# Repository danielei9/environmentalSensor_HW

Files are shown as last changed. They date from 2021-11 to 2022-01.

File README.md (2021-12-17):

# environmentalSensor

# EnvironmentalSensor

El proyecto consta de una placa maestra donde se pueden conectar varios sensores predeterminados como temperatura, humedad, sensor de sustrato y ruido. Esta placa (Master) se comunica mediante I2C con otra placa expansión (Slave) que se comunica con un máximo de 5 sensores de cualquier tipo mediante UART (mirar especificaciones de sensores admitidos).

Una vez adquiridas las medidas de los sensores, se procesan y son enviadas mediante LORA o 4G (gsm).
En el caso de LORA: el dispositivo “Master” envía datos a un Gateway de LORA, donde mediante un Bridge realiza el cambio LORA - MQTT y enviamos los datos a la plataforma
En el caso de 4G: se envía directamente a través de MQTT.
### Master:
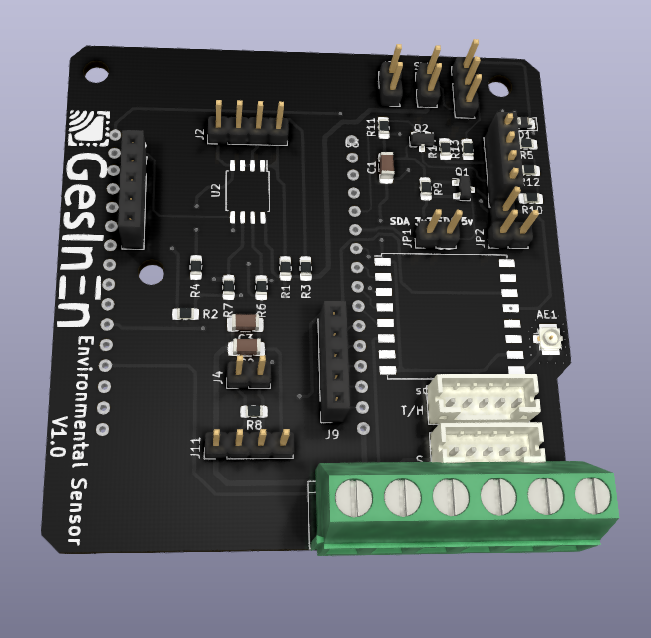
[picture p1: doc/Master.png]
Master


### Slave:

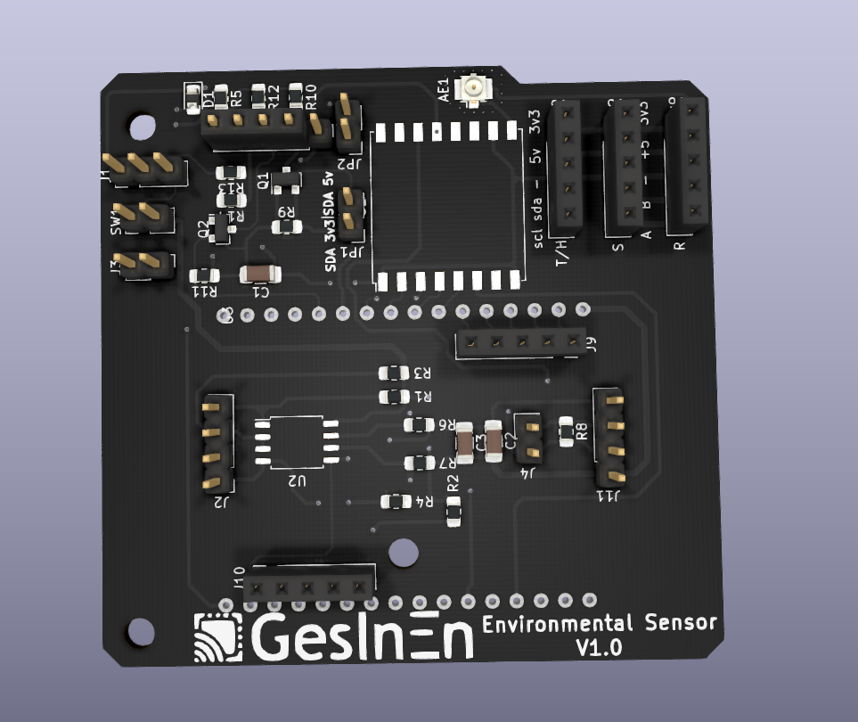
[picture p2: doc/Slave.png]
This is an image


# **Contents**
- [**Project**](#firmware-hardware-module)
- [**Contents**](#contents)
- [**Pre requirements**](#pre-requirements)
- [**Getting started**](#getting-started)
- [**Project structure**](#project-structure)
- [**Firmware**](#firmware)
  - [**Master Code**](#master-code)
  - [**Slave Code**](#slave-code)
  - [**Measures**](#measures)
- [**Deployment**](#deployment)

# **Pre requirements**
This Project is being developed using `Platformio` in Visual Studio Code so you need to have being installed it and dependences. 

- Install Platformio in Visual Studio Code
# **Getting started**
1. Clone the repository
```
git clone https://github.com/ycansam/environmentalSensor_HW
```
Now you can start with the implementation of new features to comunicate with the ttgo and arduino nano

# **Project structure**
```
environmentalSensor_HW/
    ├──  doc/
    ├── Firmware/
        ├── Master/
        ├── PruebaLora/
        ├── Slave_FW_1_0
    ├── Hardware/
        ├── Master/
        ├── Slave
    ├── tests/
```

## **Enviromental devices**
Enviromental devices are the core of the application. These devices are a modular sensor hub that can contain multiple sensors according to user requirements. Multiple devices are grouped on the same gateway.
<br>
# **Firmware**
### **MASTER CODE**
#### **DEFINING CONEXION `4G` or `LORA`**
In file `Firmware/Master/main.cpp`.
* Use **#define PROTOCOL_4G** to use 4G comunication
* Use **#define PROTOCOL_LORA** to use Lora comunication
``` c++
#define PROTOCOL_4G
//#define PROTOCOL_LORA
unsigned long mill = 0;
#include <../lib/PublishersClient.h> // After defining the comunication include this libraries
#include <Wire.h>
```
##### **DEFINING 4G VARIABLES**
Change this variable acording to your SIM
In file `Firmware/Master/lib/PublishersClient.h`.
* GPRS: "orangeworld"
* GPRSUser: "orange"
* GPRSPass: "orange"
* SIMPin: null 

``` c++
#include <../lib/Protocol4G.h>
Protocol4G protocol4G(GPRS, GPRSUser, GPRSPass, SIMPin); // constructor normal
Publisher *publisher = &protocol4G;            
```

### **Setting Up the Conexion `TLS MQTT`**
##### **Configure if using `4G COMUNICATION`**
If is it needed to change the broker, username or etc on the MQTT connection you need to change this parameters in class Protocol4G in Firmware/Master/lib
``` c++
const char broker[] = "broker";
int port = port(int);
const char *username = "userBroker";
const char *password = "passBroker";
// example
// codigoPostal/ambiental/idDispositivo/
char topic[] = "46701/ambiental/1/";
const char topicSubscribed[] = "gesinen/#";
```
### **Send** `MQTT` **via 4G**
```
TOPIC /46701/ambiental/1/#
```
``` c++
// JSON MESSAGE EXAMPLE
function sendData(uint8_t *arrayData){
 ..
 String message = "{\"deviceEui\":1,\"value\": 25.222,\"type\": \"co2\", \"unit\": \"ppm\"}"
 ..
 }
```
Body:
| Name | Type | Required | Description |
| --- |:---:|:---:|:---|
| deviceEui | `string` |  ✓ | DeviceEui  |
| value | `float` |  ✓ | Measure's value |
| unit | `string`  |  ✓ | Measure's unit |
| type | `string`  |  ✓ | Measure's type |
### **Request data from Slaves**
Using comunication I2C, pins using TTGO
* SDA: 21
* SCL: 22
``` c++
// Defining
SlaveController slaveController(21, 22);
```
``` c++
// Setup
// Initialize the I2C Master Comunication
slaveController.initMaster();
```
### SlaveController Fcuntions
#### Request data to a specific slave
``` c++
      byte* requestMeasuresToSlave(uint8_t, uint8_t){...}
      @param slaveAddress -> Slave address in Hexadecimal
      @param bytesToRequest -> number of Bytes
      @returns *byte -> byte array
```

``` c++
    // Example
      byte *arrayData = slaveController.requestMeasuresToSlave(0x20, bytesToRequest);
      printBytesArray(arrayData, bytesToRequest);
```

#### Scan Slaves
Scans the I2C conexion looking for slaves
``` c++
    void scanSlaves(){..}
    // prints the Slaves addresses
    // prints "Not Found" if didnt found any slave connected
```

## **SLAVE CODE**
#### Receiving commands from master
``` c++
   void receiveEvent(int bytes)
	// Se reciben eventos del maestro mediante comandos especificados en la cabezera del archivo main
```
Se inicializan los sensores y se duermen cuando se inicializa el esclavo.
El esclavo se inicializa con via I2C con una direccion
#### Inicializando el esclavo
``` c++
setup(){...

   Wire.begin(I2C_SLAVE_ADDR);
	// Se ha de definir #I2C_SLAVE_ADDR 0x20 
	// En hexadecimal
...	}
```
#### Leer comandos del maestro
``` c++
loop(){

	if (data != 0) // comprueba que el maestro ha enviado algun comando
	if (data == REQUEST_COMMAND) // dependiendo del comando ejecuta una accion u otra para posteriormente pedir un request de datos.
}
```
####Recoger las medidas de los sensores mediante semaforos
``` c++
// Recoger los datos 
void requestDataSensors();

// Ejemplo por separado
Sensor sensor1 = Sensor();
sensor1.getMeasure();
sensor1.getGasConcentration()

```

####Dormir & Despertar los sensores	
Despues de despertar y dormir cada sensor se ha de esperar 5 segundos para que vuelvan a tomar medidas y se estabilizen
``` c++
void wakeUpSensors(); // despierta los sensores
void sleepSensors(); // duerme los sensores

// Ejemplos por separado
Sensor sensor1 = Sensor();
sensor1.wakeUp();
sensor1.sleep()
```
####Recoger Informacion de Los Sensores

``` c++
void requestSensorsInformation() // recoge informacion de todos los sensores
// Ejemplo por separado
Sensor sensor1 = Sensor();
sensor1.getSensorInformation();
sensor1.getSensorType()
```

#### Envio de datos al master
Se han de enviar el array de datos con un maximo de 8 de length en cada envio para evitar errores en la lectura, Tambien se ha de hacer un flush para limpiar la Wire()
``` c++
void requestEvent()
{..}
```
# **License**
All the code in this repository is owned by [Daniel Burruchaga & Yeray Candel](https://ycansam.upv.edu.es/ & http://buchspro.com/).
Copyright © 2021, Yeray Candel. Daniel Burruchaga.
0 comments on commit cb6e9bf
Please sign in to comment.
© 2021 GitHub, Inc.
Terms
Privacy
Security
Status
Docs
Contact GitHub
Pricing
API
Training
Blog
About
Loading complete

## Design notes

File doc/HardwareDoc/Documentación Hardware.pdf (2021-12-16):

Documentación Técnica Hardware Environmental Sensor

El proyecto Environmental Sensor surge con la posibilidad de poder monitorizar los gases de nuestra atmósfera que nos rodea, tenemos una gran variedad de sensores que se pueden conectar directamente y el hardware/firmware se encarga de la detección del dispositivo, identificando el tipo de sensor, unidades de medida y valores de lectura. Supongamos un ejemplo en el cual deseamos añadir un sensor nuevo al proyecto, simplemente conectando éste con la placa slave nos sobrará para empezar a leer sus medidas desde la web.

El hardware del proyecto consta de 2 placas de lógica (Master / Slave)y 1 de alimentación.

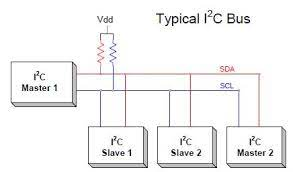
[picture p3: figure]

Estas placas, Master y Slave se comunicarán mediante comunicación I2C, teniendo un máximo de 127 Slaves conectados al Master, dando así la capacidad de leer 635 sensores (5 en cada slave).
PLACA MASTER

El Master es el encargado de despertar del modo deepSleep al slave. La función del Master se basa en las comunicaciones ( 4G,Lora,modbus,I2C ). Este módulo también tiene la posibilidad de Update OTA (Actualización sobre el aire, mediante comunicación LTE/4G es posible actualizar el dispositivo).

Características técnicas:
- ESP32
- GPS SIM7000 / SIM7070 (temporalmente no hay soporte para sim7070)
- LORA OTA
- 4G/LTE
- MODBUS
- I2C

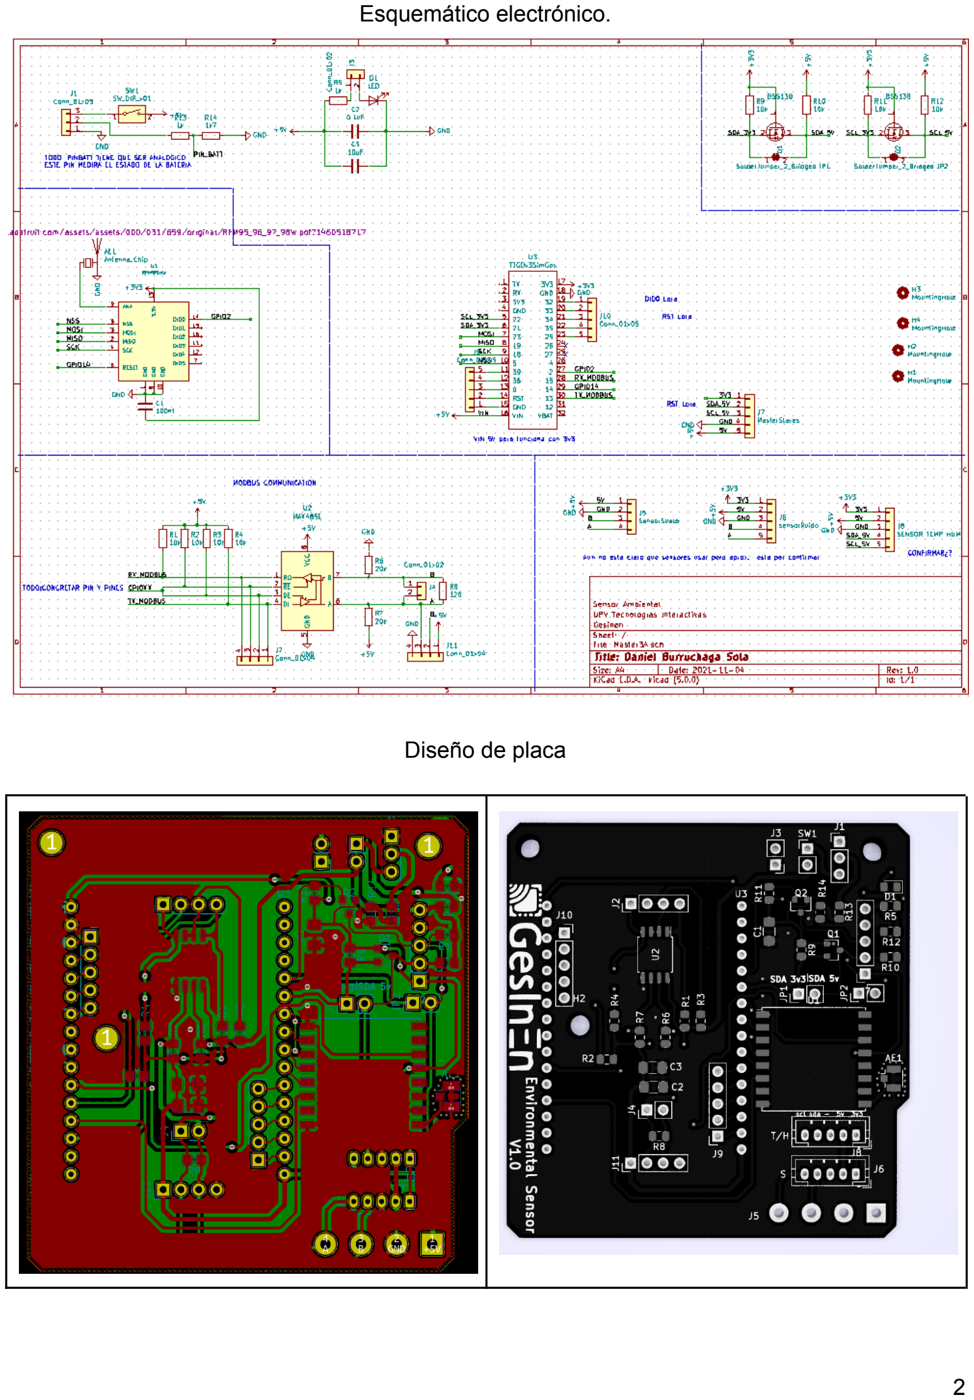
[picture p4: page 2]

Esquemático electrónico.

Diseño de placa

Los módulos del hardware se muestran a continuación:

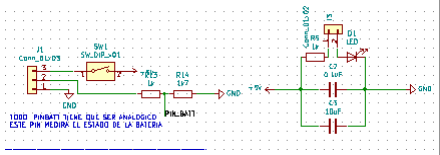
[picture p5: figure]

Módulo de alimentación encargado de la entrada externa de voltaje para su alimentación a través de la placa de Alimentación, también consta de un LED de estado para comprobar su funcionamiento

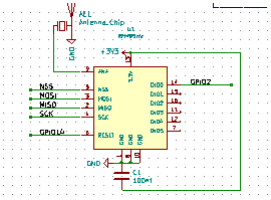
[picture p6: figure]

Módulo comunicaciones LORA, consta del RFM95X, un conector coaxial SMD para la antena de 868Mhz. Este módulo se comunica mediante SPI con el micro ESP32.

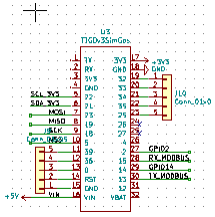
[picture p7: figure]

TTGO SIM 7070 / 7000, encargado de las comunicaciones GPS, 4G/LTE, SPI, I2C… Consta de un SIM7070 / 7000 para la comunicación con el GPS y un ESP32 como microcontrolador.

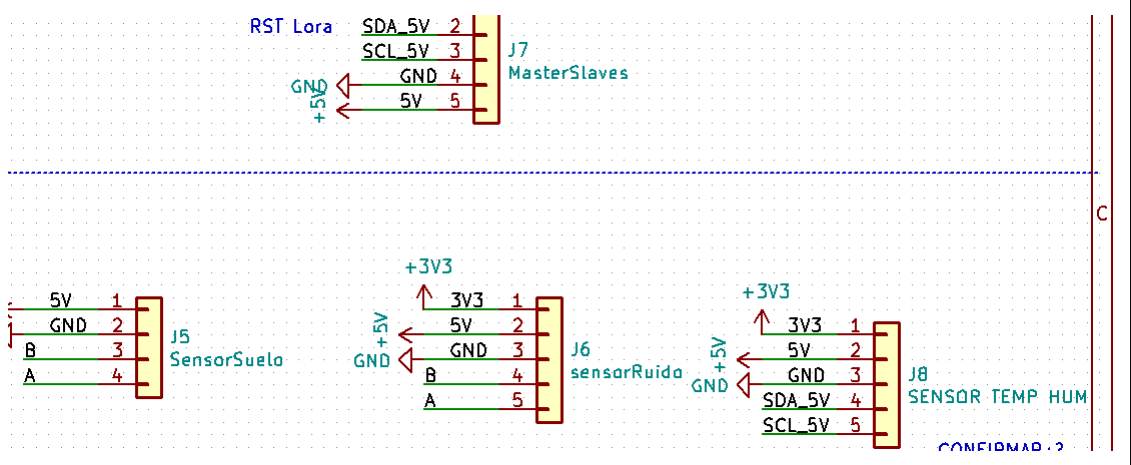
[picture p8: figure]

Conectores para comunicar los sensores fijos del master como Temperatura Humedad / FloorSensor / Sensor de Ruido y la comunicación con los slaves.

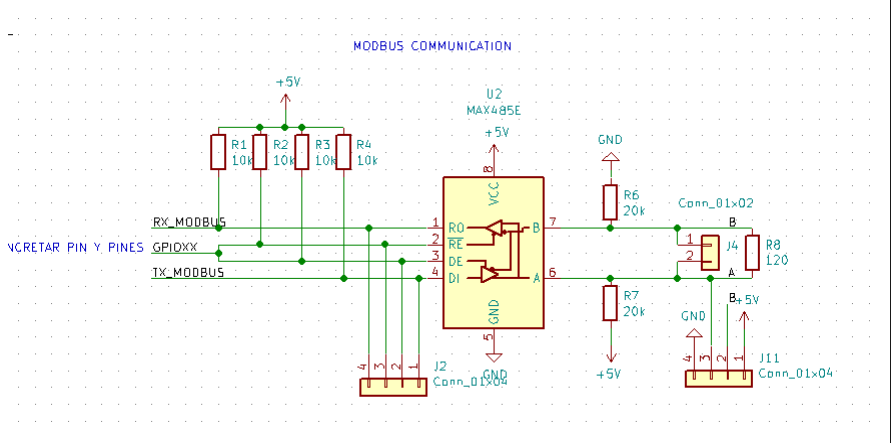
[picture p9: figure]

Modbus communication consta de un MAX485 para el cambio de Modbus A/B, a UART mediante un control de estado con un pin aparte de la UART para poder conseguir comunicación full duplex mediante los dispositivos.

Conversor de nivel lógico opcional para poder utilizar el arduino micro de 3v3 en vez del de 5V, en este caso no ha sido implementado ya que no era necesario, pero existe la posibilidad.

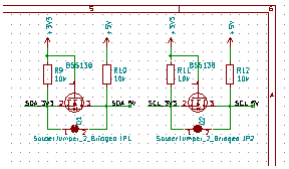
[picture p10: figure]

PLACA SLAVE

El Slave se encarga de comunicarse mediante UART con un máximo de 5 sensores por slave conectado, actuando como un multiplexor de UART controlado por I2C.

Características técnicas:
- ATMEGA328PB 5V, se puede usar tanto como chip integrado en la placa, o también tiene la posibilidad de conectar un Arduino Micro de 5V, en su lugar.
- 5 Conectores JST 2mm por placa para el conexionado de los sensores.
- I2C para la comunicación con el Master
- Capacidad de entrar a modo deepSleep al slave mediante el Master o a los sensores desde el propio Slave para mejorar su consumo energético.

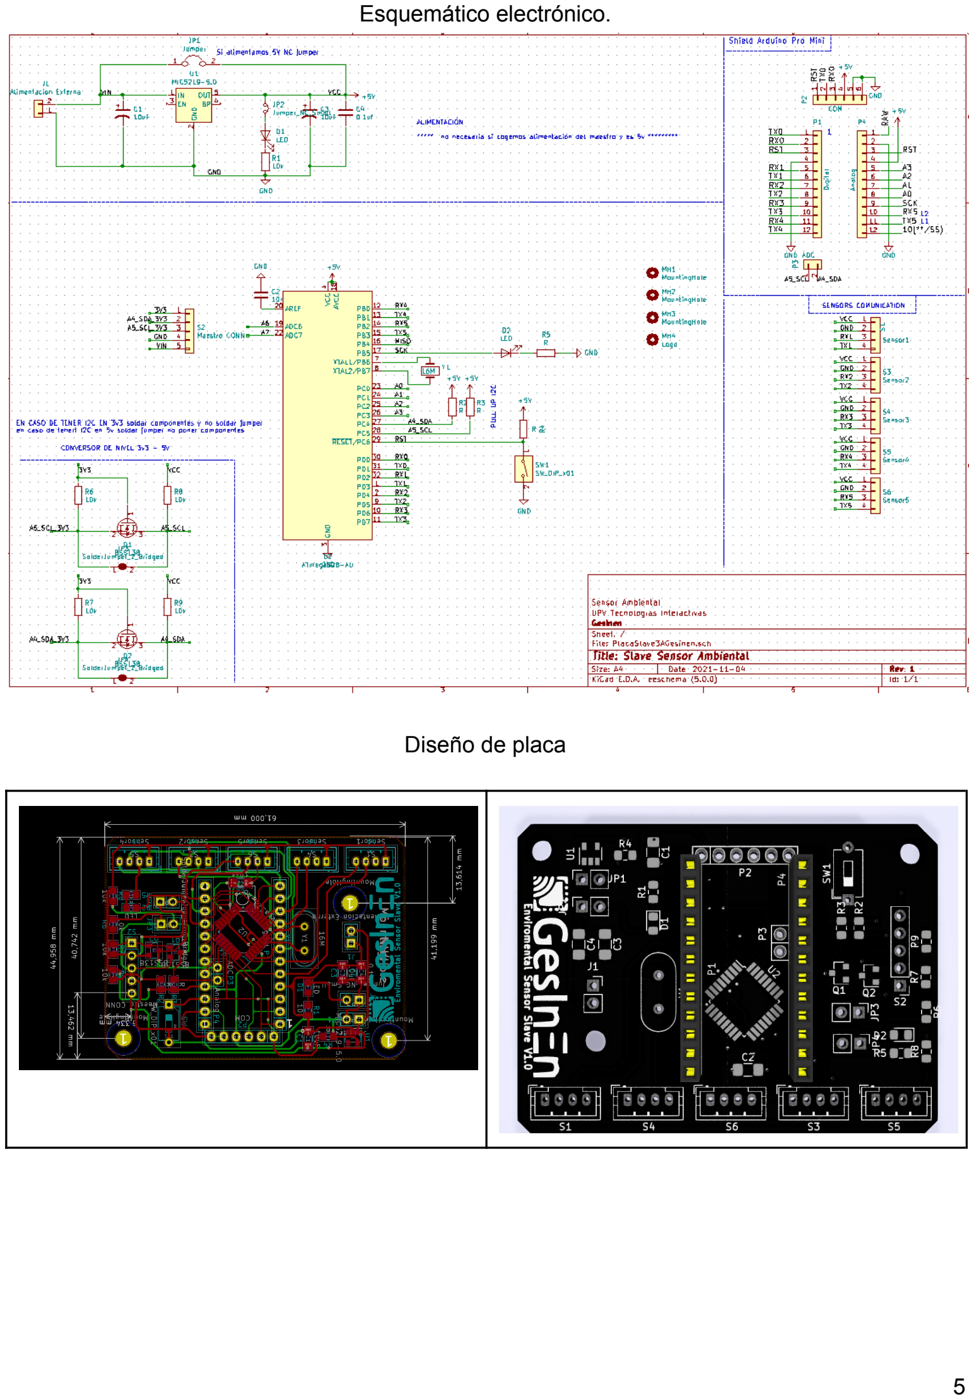
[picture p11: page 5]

Esquemático electrónico.

Diseño de placa

Los módulos del hardware se muestran a continuación:

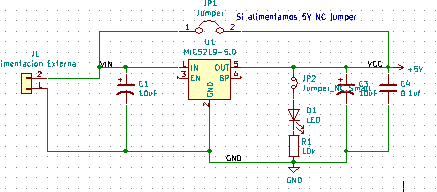
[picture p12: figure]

Módulo de alimentación encargado de la entrada de voltaje para alimentar al slave en caso de que el Master no alimente al slave

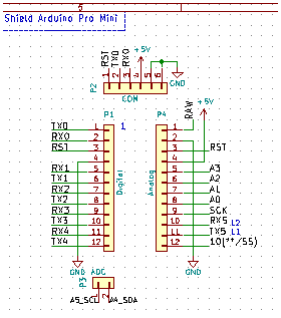
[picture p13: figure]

Conector para Arduino Micro

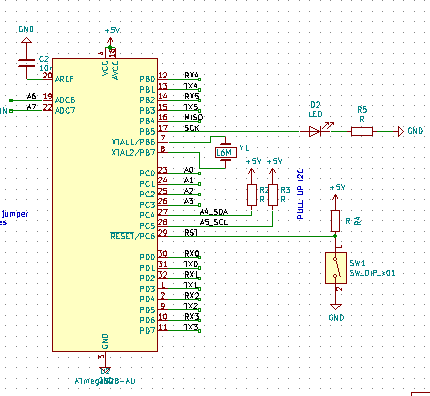
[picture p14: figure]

Modulo ATMEGA328PB en caso de tener un arduino micro y querer implementar el ATMEGA328 integrado en la placa será necesario implementar este módulo con un condensador para evitar ruidos en la entrada de referencia, un cristal de cuarzo de 16Mhz, las resistencias de pull up para I2C son personalizables dependiendo del ancho de banda necesario para la transmisión de datos, el pulsador/switch es necesario ya que es para el reset después de programar el dispositivo.

Conector para un conversor USB/TTL de 5v, para programar el atmega328PB

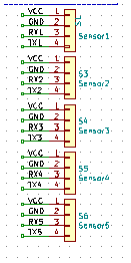
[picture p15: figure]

Conectores JST 1x4 2.00mm, donde se conectan los sensores mediante conectores.

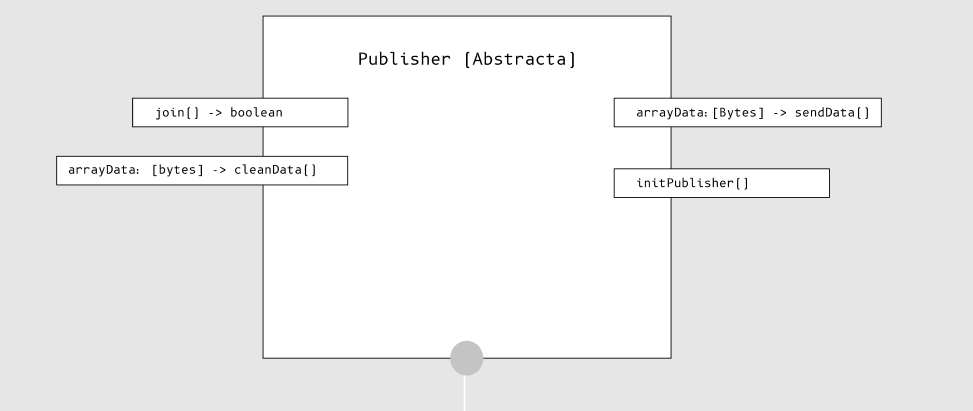
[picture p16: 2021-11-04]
doc/Schematic/DiseñoClasePublicador.png

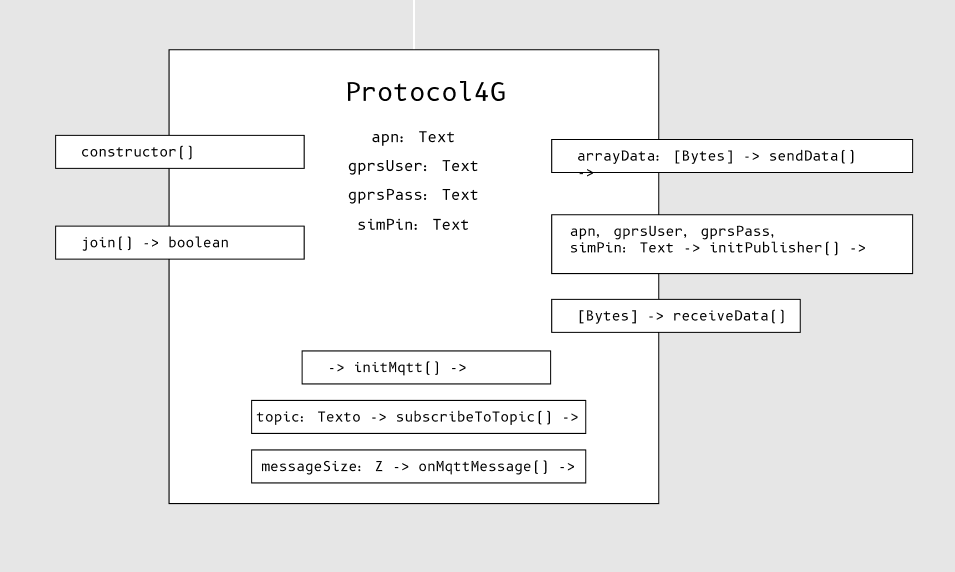
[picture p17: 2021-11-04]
doc/Schematic/DiseñoClaseProtocolo4G.png

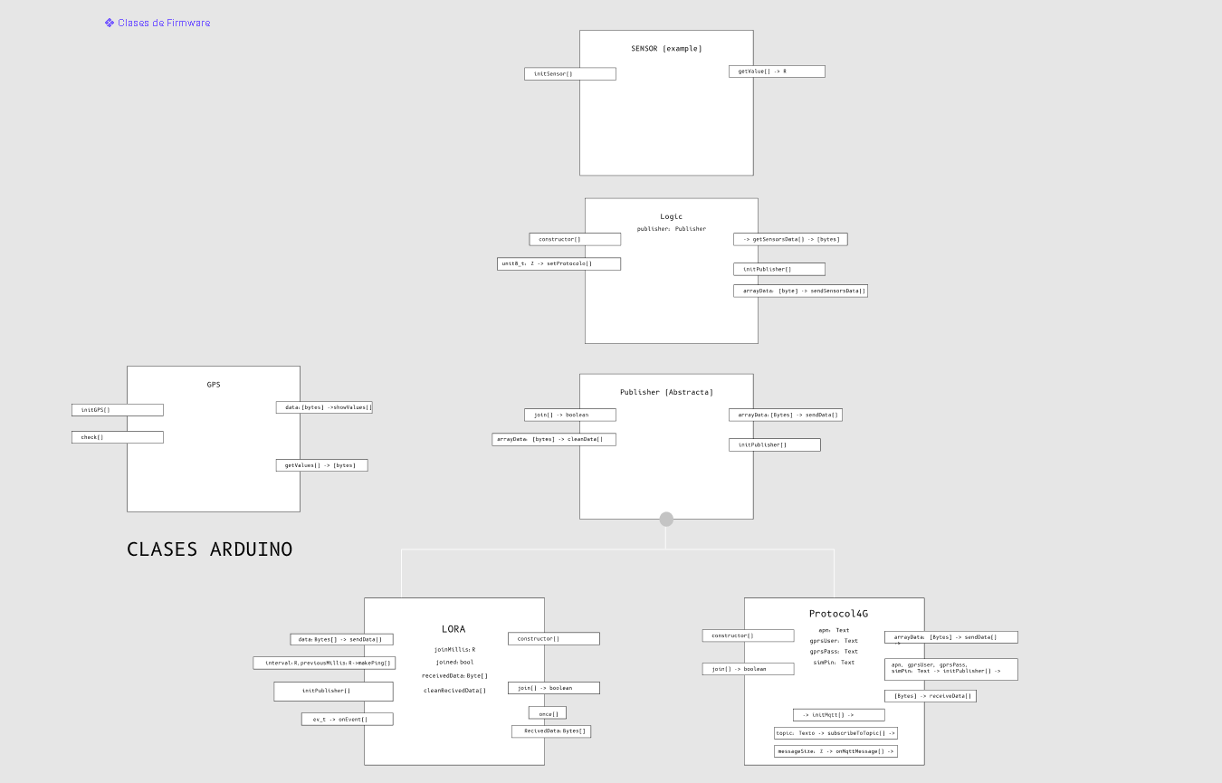
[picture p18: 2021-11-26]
doc/Schematic/Diseños Generales.PNG

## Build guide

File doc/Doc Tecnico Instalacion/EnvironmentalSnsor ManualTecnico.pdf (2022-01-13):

### Manual Técnico

Proyecto: [EnvironmentalSensor]

### GESINEN S.L

[2022]

EnvironmentalSensor | Página 1 de 5
MANUAL TÉCNICO

## MANUAL TÉCNICO

## CONTENIDO

4. Herramientas Utilizadas para el Desarrollo........2

MANUAL TÉCNICO

## 1. Objetivos

Sírvase este documento para especificar las características técnicas del EnvironmentalSensor V1.0 de Gesinen.

1.1 Objetivos Específicos.

- Descripción de la instalación.
- Configuración
- Explicar características de consumo.

## 2. Alcance

Este documento está dirigido a: __TÉCNICO________________

Conocimientos básicos en: ____ELECTRÓNICA__________________

## 3. Requerimientos Técnicos

- Dispositivo Environmental Sensor (incluyendo panel solar si consta)
- Software Environmental Sensor (disponible en github gesinen)
- Sensores a instalar
4. Herramientas Utilizadas para el Desarrollo.

Enlistar los diversos programas que fueron utilizados para el desarrollo del software y explicar el motivo para el cual se utilizaron.

- Kicad
- Proteus

## 5. Instalación

Si consta de panel solar, será necesario instalarlo justo encima del dispositivo, a unos entre los 20 y los 40 grados de inclinación.

Si consta de entrada de alimentación por alumbrado público, será necesaria su instalación a través de las regletas disponibles.

Mediante los conectores en el lateral derecho podremos conectar los sensores necesarios.

MANUAL TÉCNICO

## 6. Configuración

Las posibles configuraciones son a través de la alimentación debido a que puede funcionar por panel solar, entrada de alumbrado público 230V y alumbrado público nocturno 230V, más todas las permutaciones posibles de estas.

Ver uso de batería recomendación 2 baterías PANASONIC 18650 3V7 + alumbrado nocturno + Panel solar 20W 5v

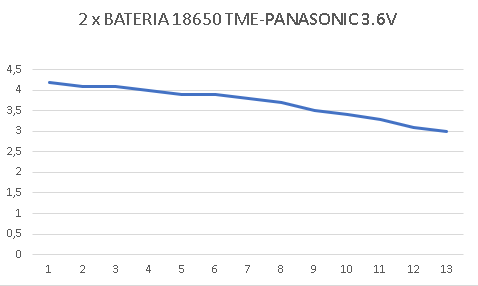
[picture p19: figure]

X = tiempo-horas // Y =Voltaje 2baterias + panel solar

El dispositivo se configura automáticamente cuando conectamos un sensor. En el código previamente grabado en el micro deberemos de configurar si va a ser a través de Lora o 4g la comunicación.

MANUAL TÉCNICO

7. Datos de la Arquitectura.
- Tópico de envió definido MQTT :

gesinen/”Codigo Postal de instalación del dispositivo”/ambiental/data

- DevEUI: _____Número de serie del equipo_______________
- Proveedor: _______ORANGE____________
- Dependencias con otros sistemas: Plataforma operativa de visualización

## 8. Usuarios

El derecho de visualización de los datos esta restringido a los usuarios dados de alta en la base de datos de la plataforma.

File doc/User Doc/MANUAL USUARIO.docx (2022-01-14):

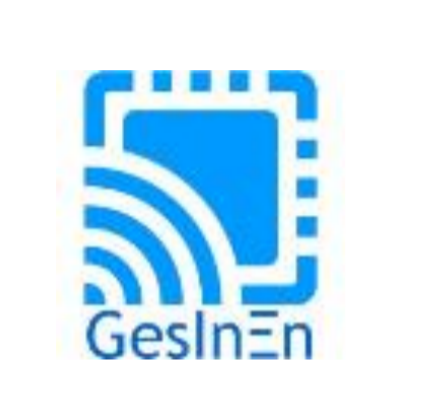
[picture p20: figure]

Dispositivos Ambientales M2

Manual de Usuario

Versión: 001

Fecha: 02/01/2022

V001

Queda prohibido cualquier tipo de explotación y, en particular, la reproducción, distribución, comunicación pública y/o transformación, total o parcial, por cualquier medio, de este documento sin el previo consentimiento expreso y por escrito de la Junta de Andalucía.

HOJA DE CONTROL

Organismo | Gesinen
Proyecto | Dispositivos Ambientales M2
Entregable | Manual de Usuario
Autor | Yeray Candel Sampedro
Versión/Edición | 001 | Fecha Versión | 02/01/2022
Aprobado por | | Fecha Aprobación | 02/01/2022
| | Nº Total de Páginas | 13

REGISTRO DE CAMBIOS

Versión | Causa del Cambio | Responsable del Cambio | Fecha del Cambio
001 | Versión inicial | Yeray Candel Sampedro | 02/01/2022

CONTROL DE DISTRIBUCIÓN

Nombre y Apellidos

Yeray Candel Sampedro

ÍNDICE

1 DESCRIPCIÓN DEL SISTEMA 4

1.1 Objeto 4

1.2 Alcance 4

1.3 Funcionalidad 4

2 MAPA DEL SISTEMA 5

2.1 Modelo Lógico 5

2.2 Navegación 5

3 DESCRIPCIÓN DEL SISTEMA 6

4 ANEXOS 10

1  DESCRIPCIÓN DEL SISTEMA
  1.1  Objeto

Este documento está diseñado para guiar a aquellos usuarios que quieran operar con el proyecto en cuestión.

  1.2  Alcance

El presente documento está destinado para aquellos usuarios que no pertenezcan a la organización o empresa propia del proyecto.

  1.3  Funcionalidad

La funcionalidad principal del dispositivo a utilizar es recoger medidas a través de unos sensores los cuales en cuestión, miden la calidad del aire. Para posteriormente a través de tecnologías como LORA o 4G, enviarlas a una plataforma en el que se visualizarán los datos correspondientes a los dispositivos adquiridos.

En la web el usuario será capaz de visualizar todas las medidas de los sensores y los datos del dispositivo tanto a través de gráficas, tablas, etc.

El usuario puede visualizar los ayuntamientos, gateways y dispositivos ubicados en un mapa en una sección de la plataforma. Además también podrá observar una media de la calidad del aire mediante una capa de interpolación.

2  MAPA DEL SISTEMA
  2.1  Modelo Lógico

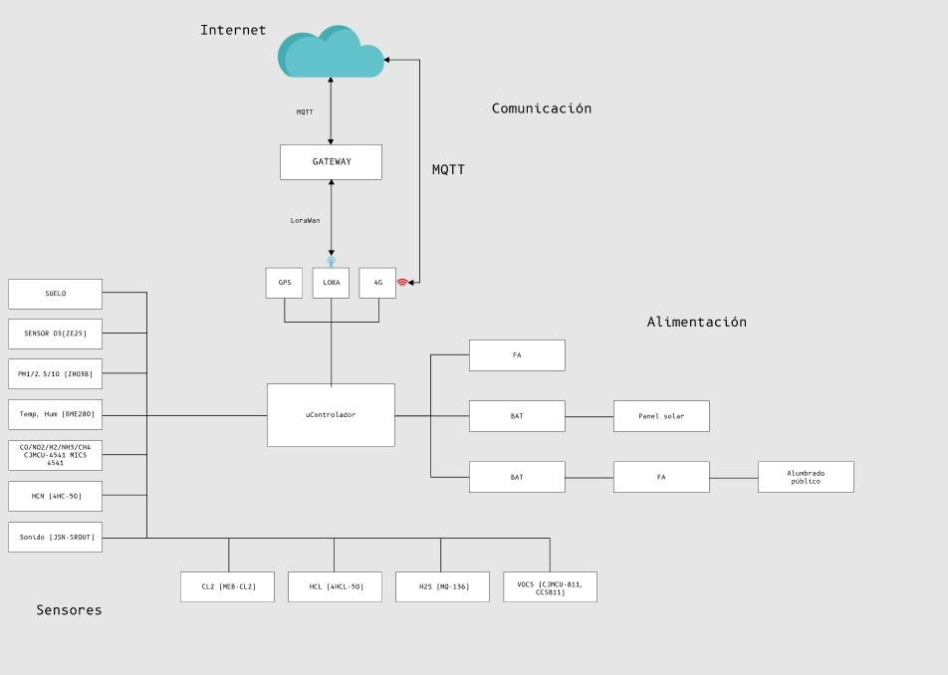
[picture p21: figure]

  2.2  Navegación

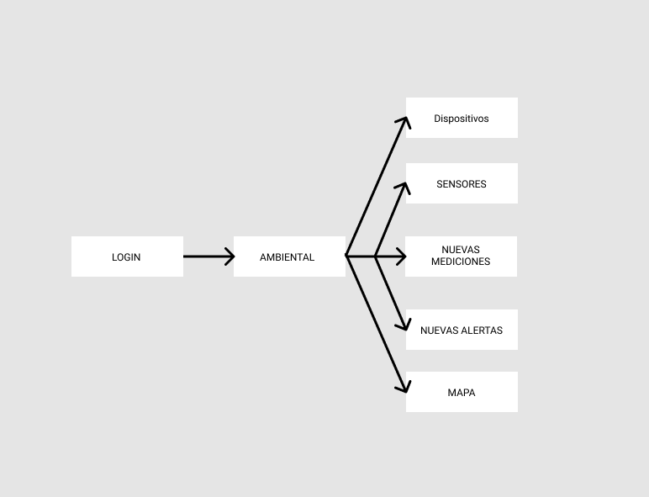
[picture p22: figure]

La primera página disponible será el login, en el que se deberá introducir los datos de usuario y contraseña previamente obtenidos. Seguidamente se pasará a un dashboard ambiental en el que habrá distintas opciones de selección para visualizar los datos.

En la primera opción se podrán visualizar los dispositivos con sus respectivas características, id del dispositivo, nombre, posición transformada a coordenadas, y el estado operativo o apagado.

En sensores se podrán ver los distintos sensores pertenecientes a los dispositivos ligados a la id del dispositivo.

En nuevas mediciones se visualizarán las últimas mediciones obtenidas por los sensores.

En las alertas saldrán avisos de posibles medidas peligrosas para el ambiente.

Por último se podrá visualizar el mapa con los dispositivos asociados al usuario y también se podrá consultar un mapa de interpolación.

3  DESCRIPCIÓN DEL SISTEMA

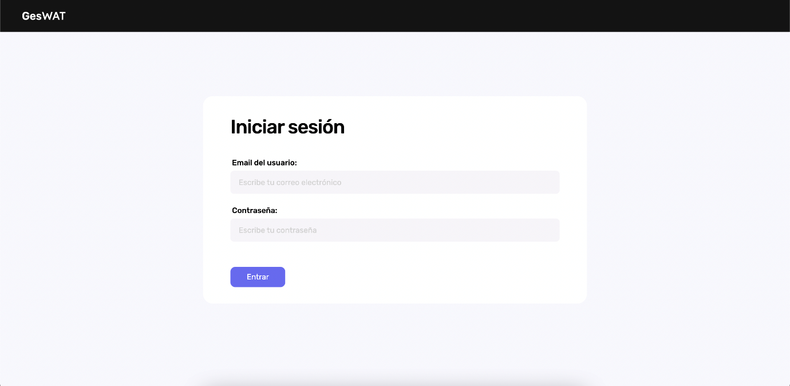
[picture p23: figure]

Pantalla de inicio de sesión.

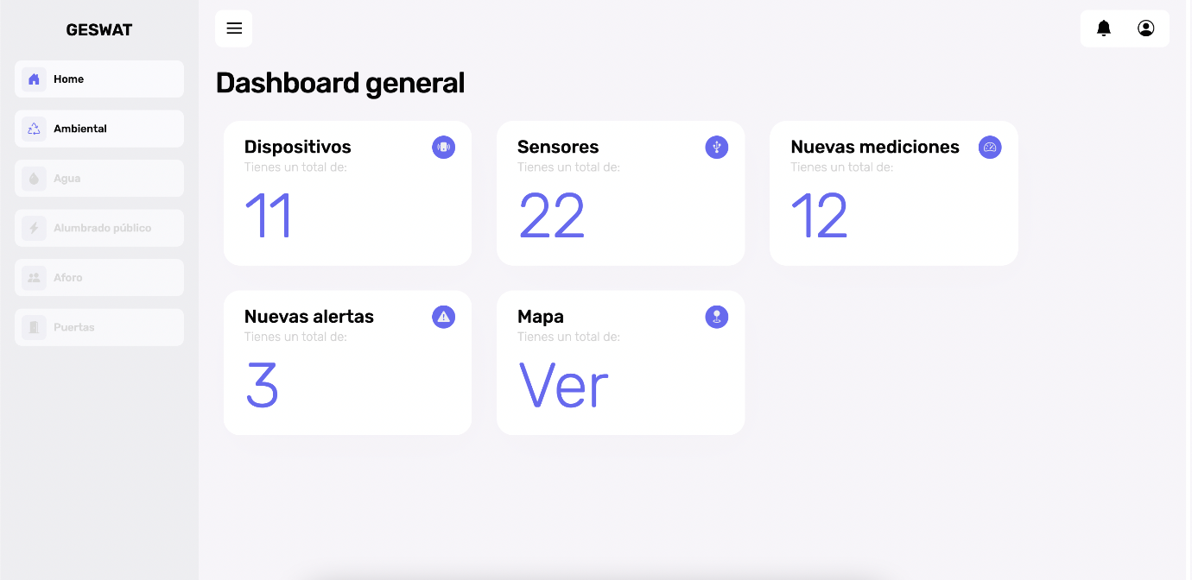
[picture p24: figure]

Pantalla del dashboard

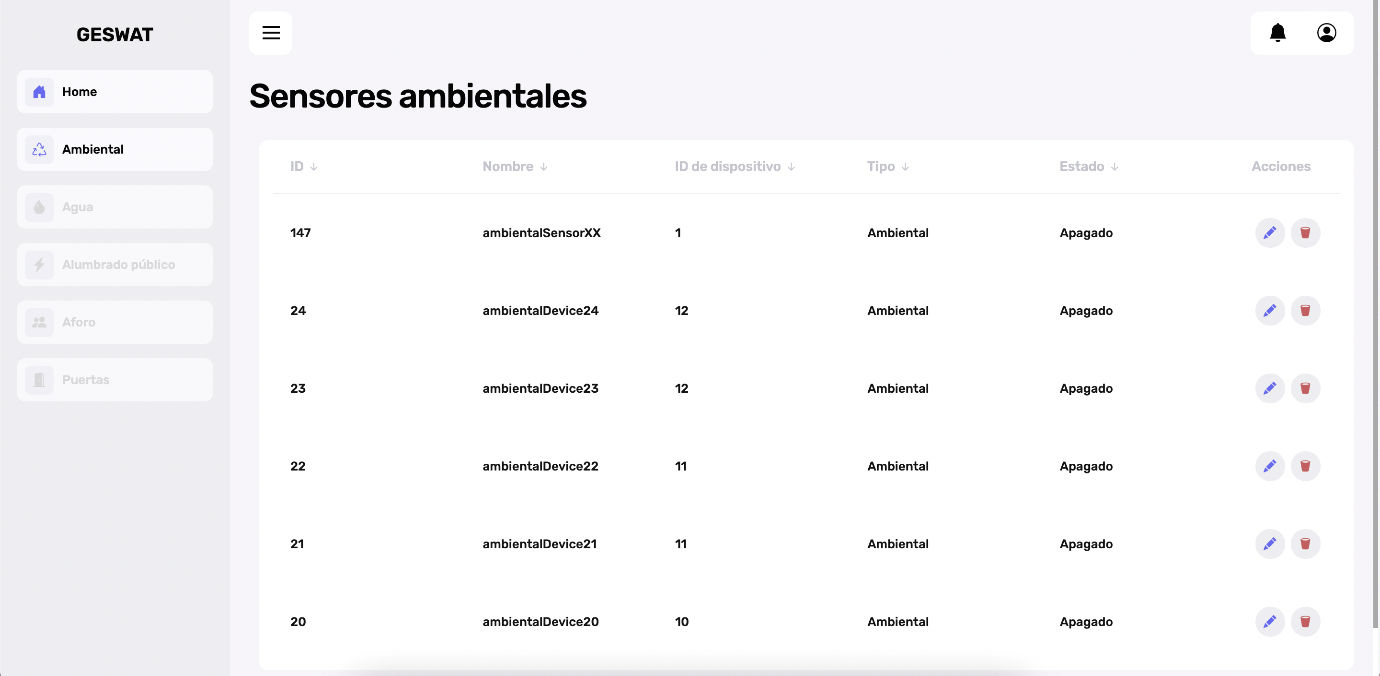
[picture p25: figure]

Pantalla de los sensores ambientales

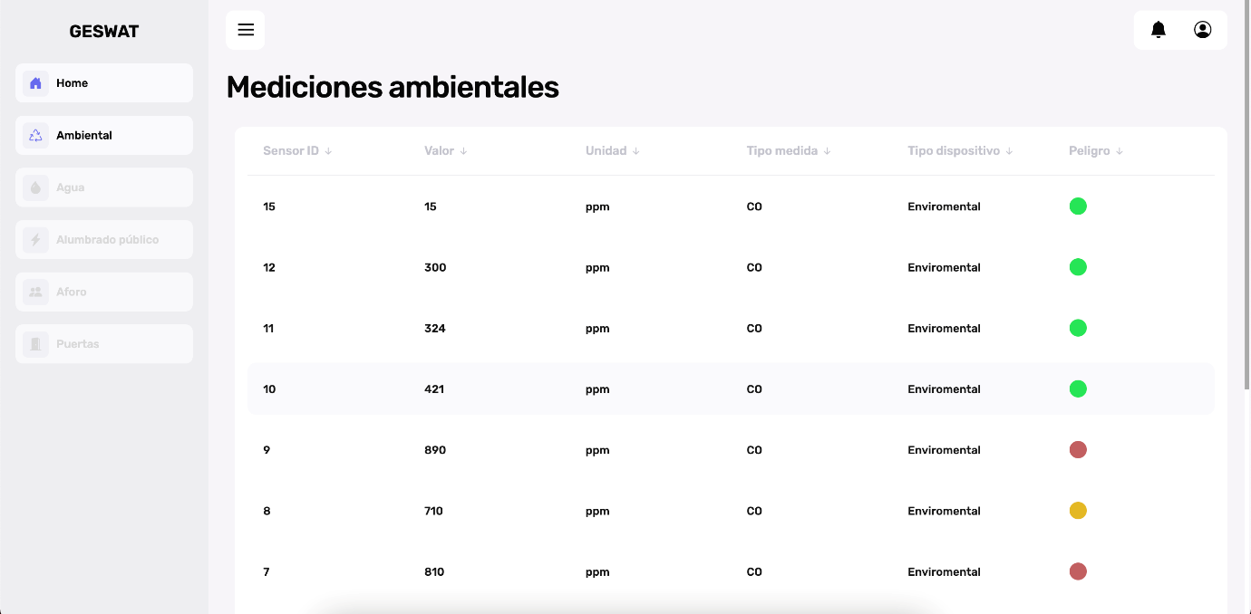
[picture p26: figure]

Pantalla de las ultimas mediciones.

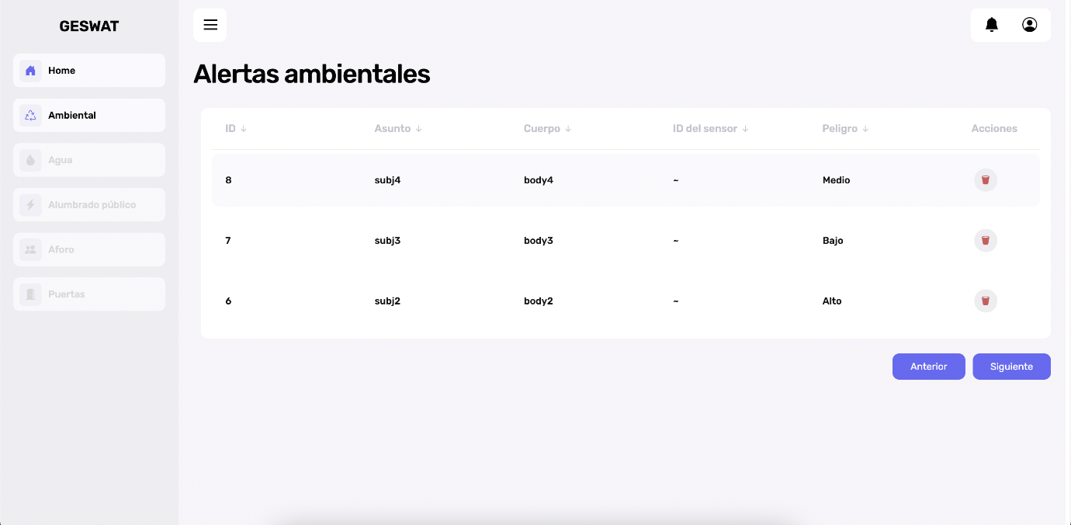
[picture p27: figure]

Pantalla de alertas recibidas

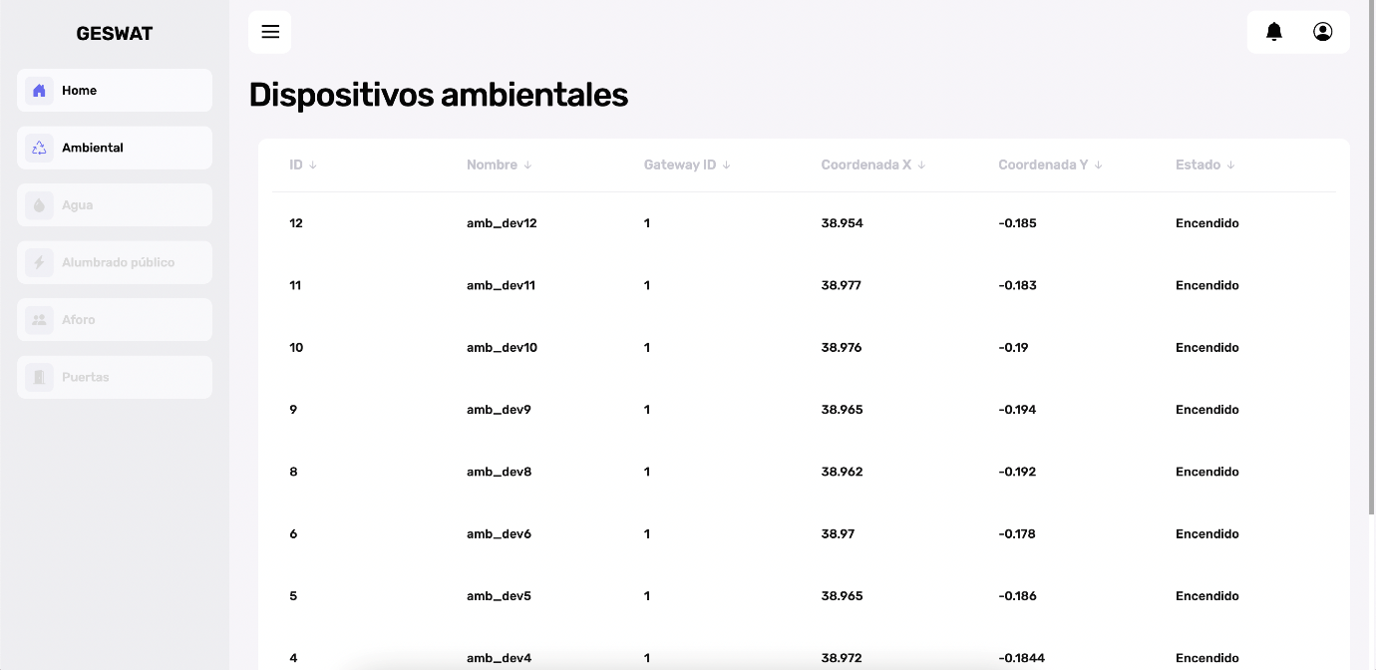
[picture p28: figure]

Pantalla de los dispositivos ambientales.

y anexos de referencia.

4  GLOSARIO

Término | Descripción
LORA | Protocolo de comunicación de transmisión de datos.
MQTT | Protocolo de comunicación de transmisión de datos.
4G | Protocolo de comunicación de transmisión de datos.
GATEWAY | Dispositivo de transmisión de datos via LORA

Dispositivos Ambientales M2 Manual de Usuario Gesinen

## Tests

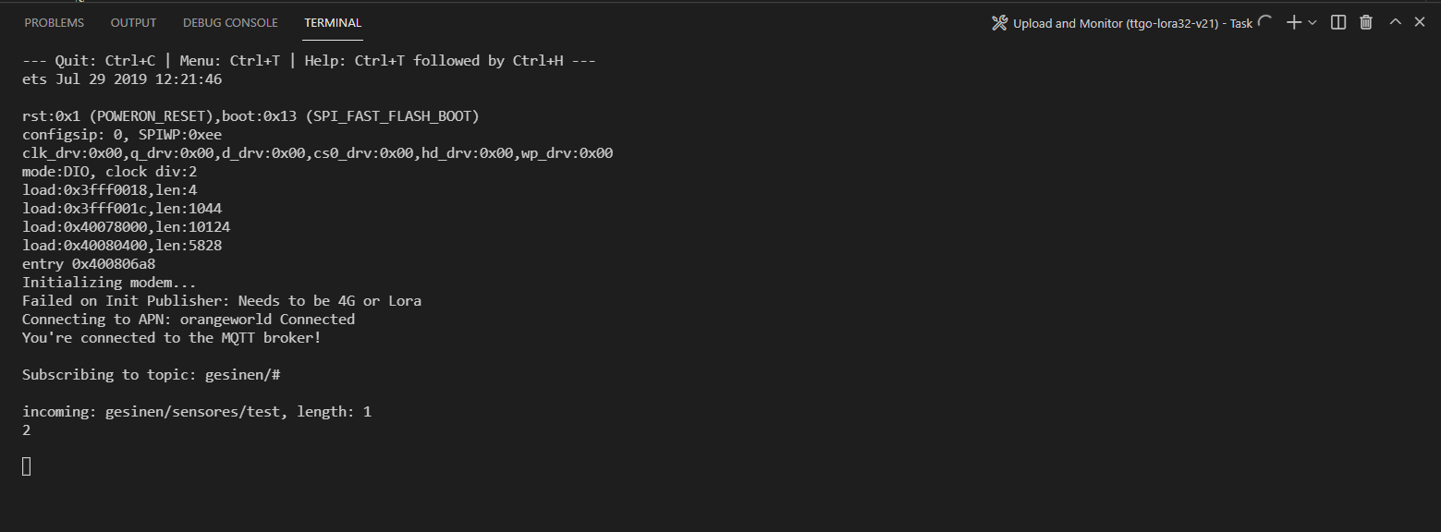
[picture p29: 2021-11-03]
tests/test_recepcion_MQTT_4G.png

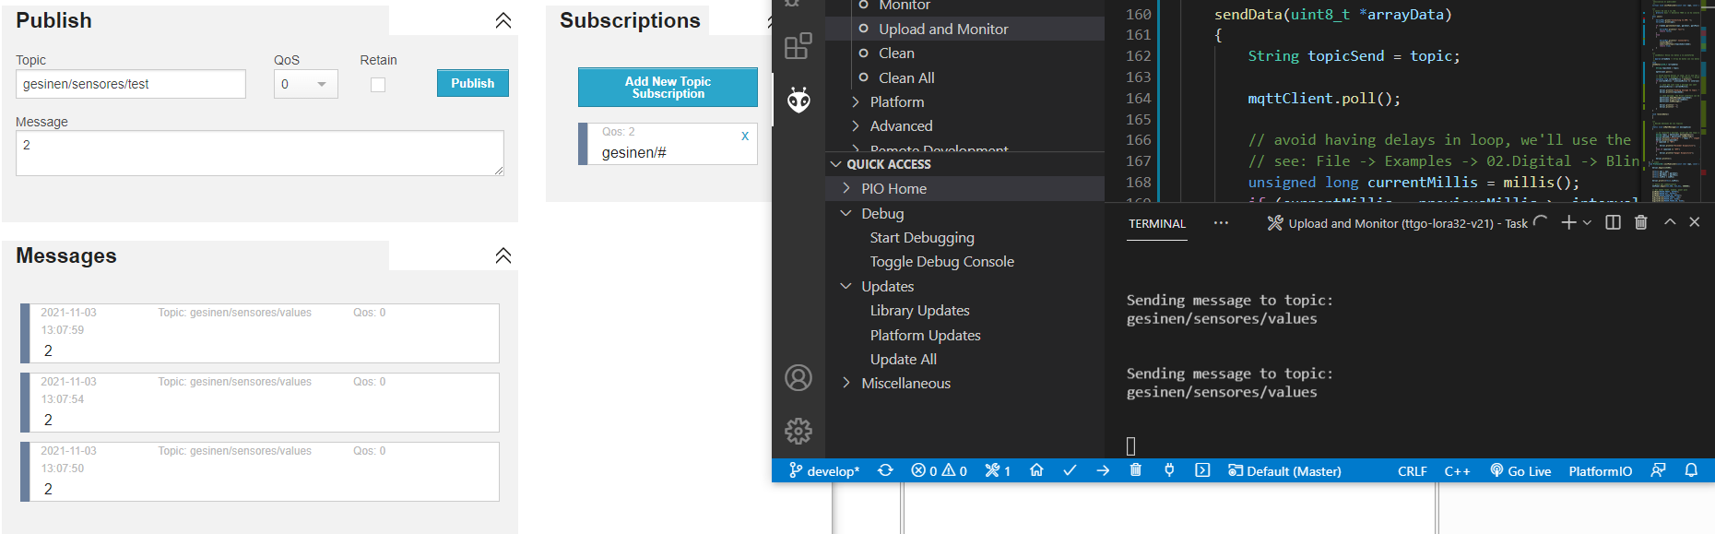
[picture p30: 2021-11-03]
tests/test_send_MQTT_4G.png

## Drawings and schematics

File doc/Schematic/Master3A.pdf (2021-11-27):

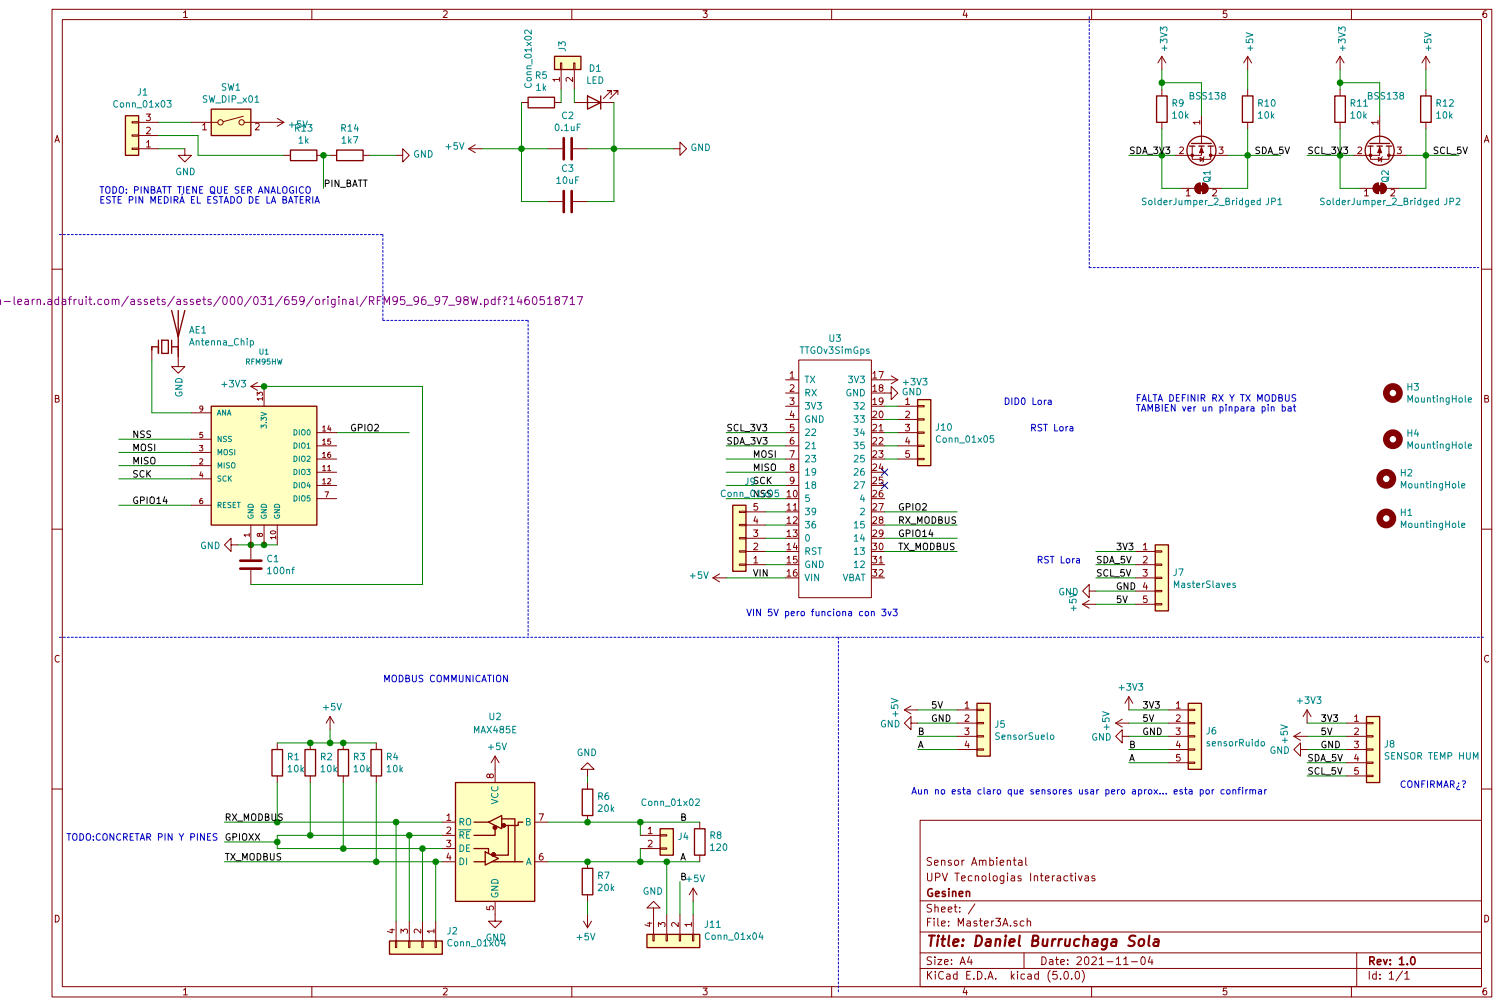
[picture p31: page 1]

J1 Conn_01x03 TODO: PINBATT TIENE QUE SER ANALOGICO

TAMBIEN ver un pinpara pin bat R13

SCK MISO MOSI GND

https://cdn-learn.adafruit.com/assets/assets/000/031/659/original/RFM95_96_97_98W.pdf?1460518717

1 GND 10 DIO3 11 DIO4 12 3.3V 13 DIO0 14 DIO1 15 DIO2 16 MISO 2 MOSI 3 SCK 4 NSS 5 RESET 6 DIO5 7 GND

FALTA DEFINIR RX Y TX MODBUS

File: Master3A.sch Sheet: / Gesinen UPV Tecnologias Interactivas Sensor Ambiental

Id: 1/1 Title: Daniel Burruchaga Sola

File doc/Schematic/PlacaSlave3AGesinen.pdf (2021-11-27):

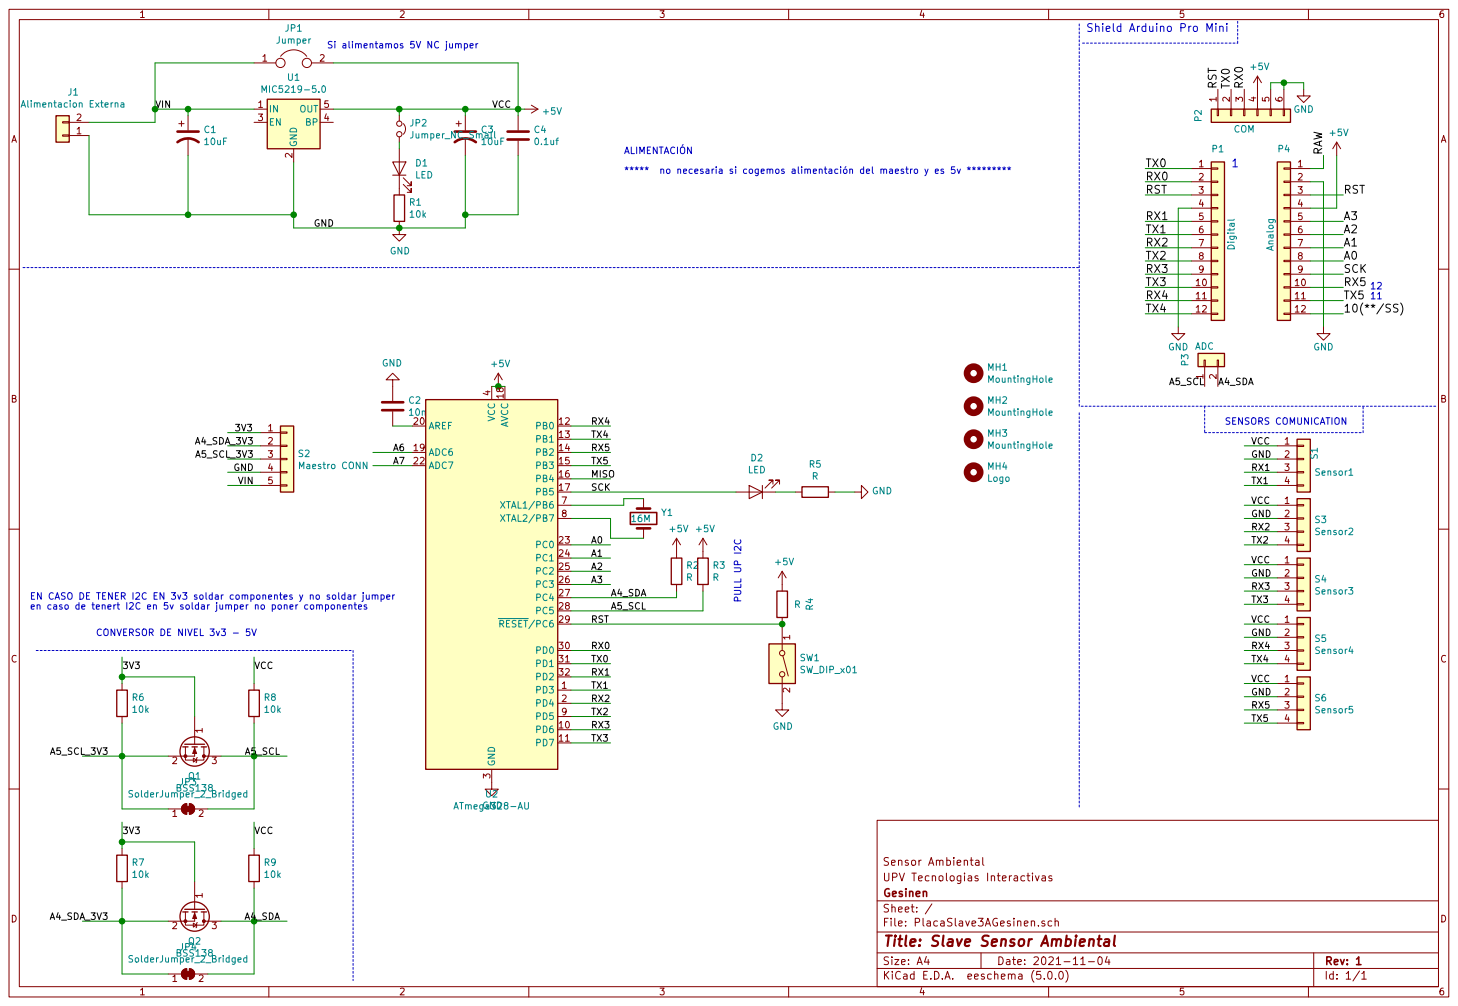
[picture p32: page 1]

A0A1A2A3 Shield Arduino Pro Mini 1

***** no necesaria si cogemos alimentación del maestro y es 5v ********* VIN GND

JP3 SolderJumper_2_Bridged A5_SCL_3V3 A4_SDA_3V3 EN CASO DE TENER I2C EN 3v3 soldar componentes y no soldar jumper

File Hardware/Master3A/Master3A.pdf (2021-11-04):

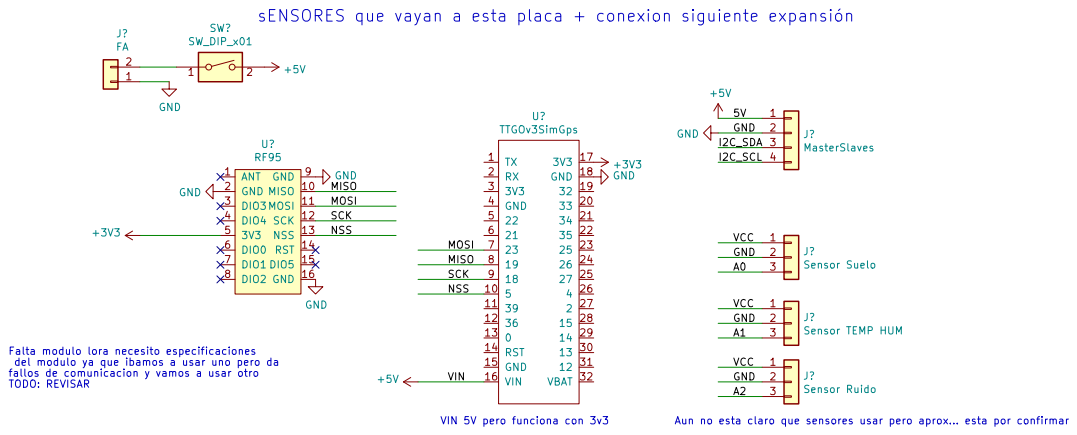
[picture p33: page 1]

+3V3 Falta modulo lora necesito especificaciones

del modulo ya que ibamos a usar uno pero da

J?Sensor Ruido VCC GND

A2 Aun no esta claro que sensores usar pero aprox... esta por confirmar +5V

File: Master3A.sch Sheet: / Gesinen UPV Tecnologias Interactivas Sensor Ambiental

Id: 1/1 Title: Daniel Burruchaga Sola

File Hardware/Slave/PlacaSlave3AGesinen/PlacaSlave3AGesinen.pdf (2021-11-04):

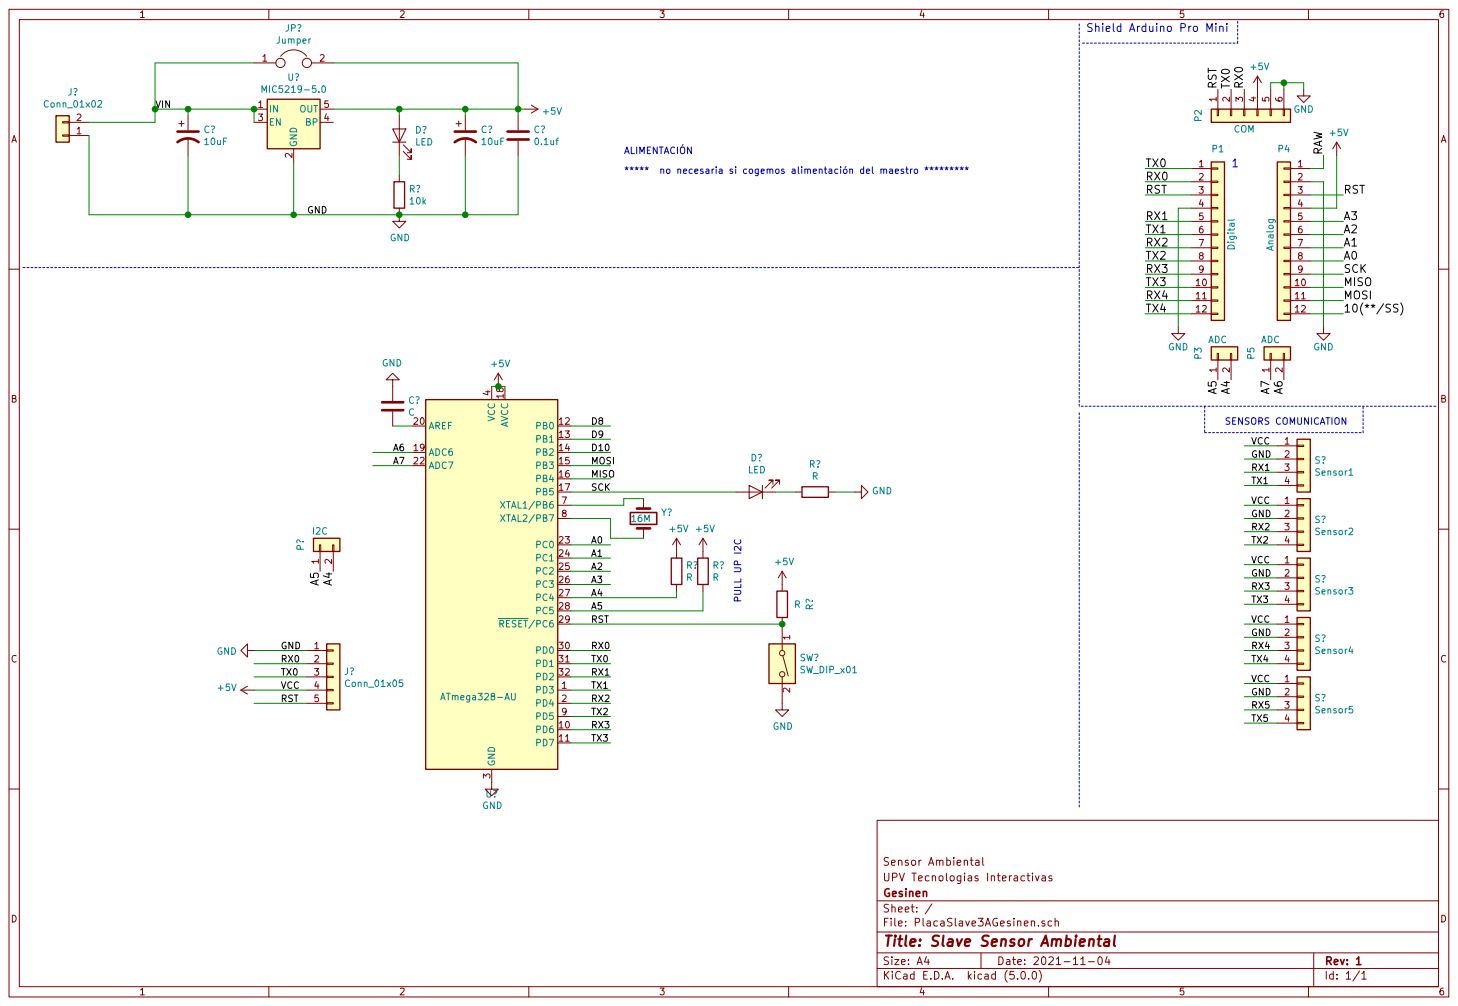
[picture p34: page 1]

ALIMENTACIÓN
***** no necesaria si cogemos alimentación del maestro *********

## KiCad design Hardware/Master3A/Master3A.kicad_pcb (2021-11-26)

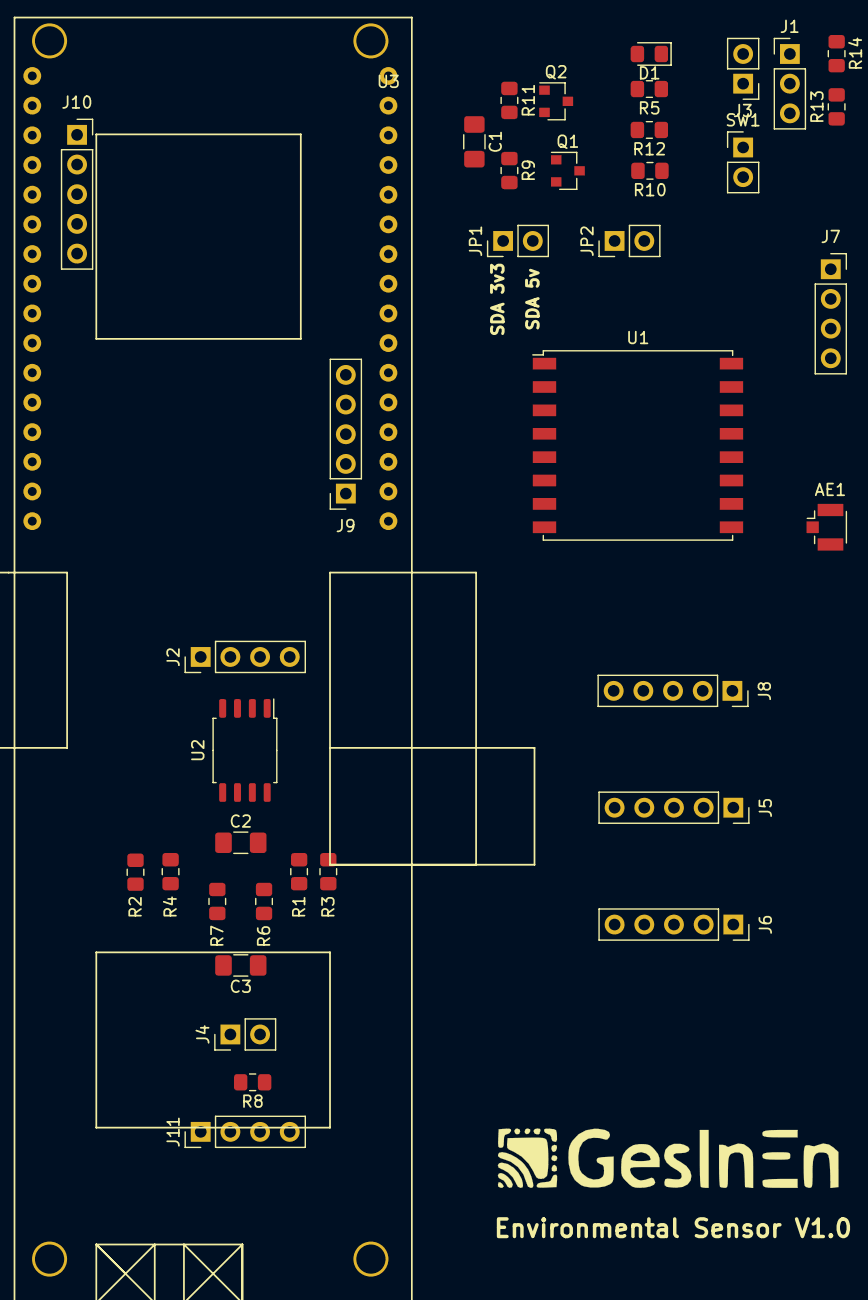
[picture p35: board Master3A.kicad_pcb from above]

Board: 2 copper layers, 39 parts (0 on the bottom side), 33 nets, no tracks yet.

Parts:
AE1: Antenna_Chip; U.FL_Hirose_U.FL-R-SMT-1_Vertical
C1: 100nf; C_1206_3216Metric_Pad1.42x1.75mm_HandSolder
C2: 0.1uF; C_1206_3216Metric_Pad1.42x1.75mm_HandSolder
C3: 10uF; C_1206_3216Metric_Pad1.42x1.75mm_HandSolder
D1: LED; D_0805_2012Metric_Pad1.15x1.40mm_HandSolder
H1: MountingHole; GesinenLogo
J1: Conn_01x03; PinHeader_1x03_P2.54mm_Vertical
J2, J11: Conn_01x04; PinHeader_1x04_P2.54mm_Vertical
J3, J4: Conn_01x02; PinHeader_1x02_P2.54mm_Vertical
J5: SensorSuelo; PinSocket_1x05_P2.54mm_Vertical
J6: sensorRuido; PinSocket_1x05_P2.54mm_Vertical
J7: MasterSlaves; PinSocket_1x04_P2.54mm_Vertical
J8: SENSOR TEMP HUM; PinSocket_1x05_P2.54mm_Vertical
J9, J10: Conn_01x05; PinSocket_1x05_P2.54mm_Vertical
JP1, JP2: SolderJumper_2_Bridged; PinHeader_1x02_P2.54mm_Vertical
Q1, Q2: BSS138; SOT-23
R1, R2, R3, R4, R9, R10, R11, R12: 10k; R_0805_2012Metric_Pad1.15x1.40mm_HandSolder
R5, R13: 1k; R_0805_2012Metric_Pad1.15x1.40mm_HandSolder
R6, R7: 20k; R_0805_2012Metric_Pad1.15x1.40mm_HandSolder
R8: 120; R_0805_2012Metric_Pad1.15x1.40mm_HandSolder
R14: 1k7; R_0805_2012Metric_Pad1.15x1.40mm_HandSolder
SW1: SW_DIP_x01; PinHeader_1x02_P2.54mm_Vertical
U1: RFM95HW; HOPERF_RFM9XW_SMD
U2: MAX485E; SOP-8_5.28x5.23mm_P1.27mm
U3: TTGOv3SimGps; TTGo

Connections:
+3V3: C1.2, J5.1, J6.1, J8.1, Q1.1, Q2.1, R9.1, R11.1, U1.13, U3.17
+5V: C2.2, C3.2, J5.2, J6.2, J7.4, J8.2, J11.1, R1.1, R2.1, R3.1, R4.1, R5.2, R7.2, R10.1, R12.1, SW1.2, U2.8, U3.16
/A: J4.2, J5.5, J6.5, J11.3, R7.1, R8.1, U2.6
/B: J4.1, J5.4, J6.4, J11.2, R6.2, R8.2, U2.7
/GPIO2: U1.14, U3.27
/GPIO14: U1.6, U3.29
/GPIOXX: J2.2, J2.3, R2.2, R3.2, U2.2, U2.3
/MISO: U1.2, U3.8
/MOSI: U1.3, U3.7
/NSS: U1.5, U3.10
/PIN_BATT: J1.2, R13.1, R13.2, R14.2
/RX_MODBUS: J2.4, R1.2, U2.1, U3.28
/SCK: U1.4, U3.9
/SCL_3V3: JP2.1, Q2.2, R11.2, U3.5
/SCL_5V: J7.2, J8.5, JP2.2, Q2.3, R12.2
/SDA_3V3: JP1.1, Q1.2, R9.2, U3.6
/SDA_5V: J7.1, J8.4, JP1.2, Q1.3, R10.2
/TX_MODBUS: J2.1, R4.2, U2.4, U3.30
GND: AE1.2, C1.1, C2.1, C3.1, D1.1, J1.1, J5.3, J6.3, J7.3, J8.3, J11.4, R6.1, R14.1, U1.1, U1.8, U1.10, U2.5, U3.18
unnamed: AE1.1, U1.9
unnamed: D1.2, J3.2
unnamed: J1.3, SW1.1
unnamed: J3.1, R5.1
unnamed: J9.1, U3.15
unnamed: J9.2, U3.14
unnamed: J9.3, U3.13
unnamed: J9.4, U3.12
unnamed: J9.5, U3.11
unnamed: J10.1, U3.19
unnamed: J10.2, U3.20
unnamed: J10.3, U3.21
unnamed: J10.4, U3.22
unnamed: J10.5, U3.23

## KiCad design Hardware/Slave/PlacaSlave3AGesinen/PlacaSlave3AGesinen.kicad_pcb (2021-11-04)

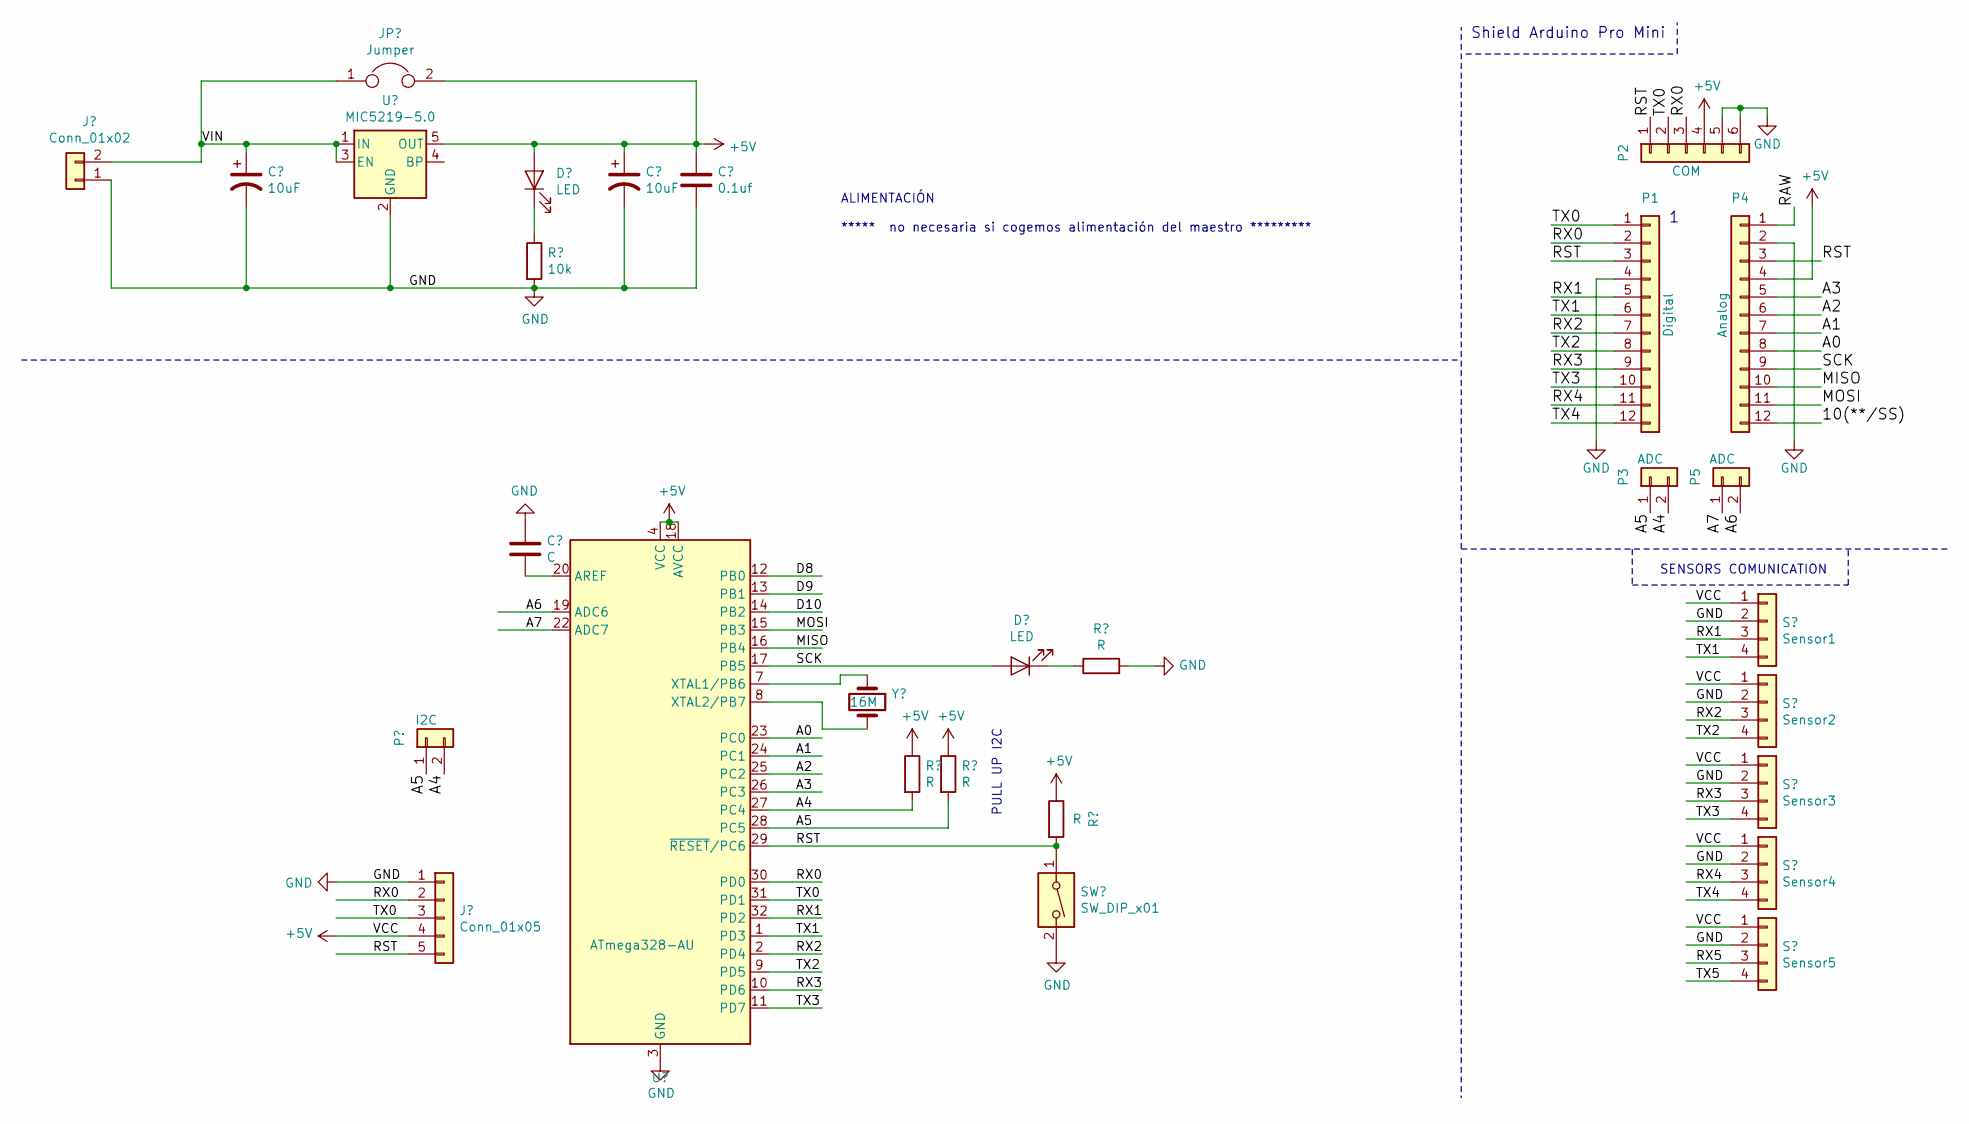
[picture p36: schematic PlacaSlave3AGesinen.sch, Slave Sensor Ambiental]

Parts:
P1: Digital; Socket_Strip_Arduino_1x12
P2: COM; Socket_Strip_Arduino_1x06
P3, P5: ADC; Socket_Strip_Arduino_1x02
P4: Analog; Socket_Strip_Arduino_1x12

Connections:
/0(Rx): P1.2, P2.3
/1(Tx): P1.1, P2.2
/2: P1.5
/3(**): P1.6
/4: P1.7
/5(**): P1.8
/6(**): P1.9
/7: P1.10
/8: P1.11
/9(**): P1.12
/10(**/SS): P4.12
/11(**/MOSI): P4.11
/12(MISO): P4.10
/13(SCK): P4.9
/A0: P4.8
/A1: P4.7
/A2: P4.6
/A3: P4.5
/A4: P3.2
/A5: P3.1
/A6: P5.2
/A7: P5.1
/RAW: P4.1
GND: P1.4, P2.5, P2.6, P4.2
VCC: P2.4, P4.4

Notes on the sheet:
Shield Arduino Pro Mini
PULL UP I2C
SENSORS COMUNICATION
ALIMENTACIÓN ***** no necesaria si cogemos alimentación del maestro *********

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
Board: 2 copper layers, 5 parts (0 on the bottom side), 5 nets, no tracks yet.

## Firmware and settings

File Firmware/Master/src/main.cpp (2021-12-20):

#include <Arduino.h>
#include <Wire.h>
#include <EEPROM.h>
#define CFG_sx1276_radio 1 // HPD13A LoRa SoC

#define DEVEUI_DEF                                 \
  {                                                \
    0x64, 0x47, 0x1d, 0xa3, 0xe1, 0x71, 0x99, 0x13 \
  }
#include <../lib/MCCI LoRaWAN LMIC library/src/hal/hal.h>

#include <../lib/MCCI LoRaWAN LMIC library/src/lmic.h>
#include <SPI.h>

#include "../lib/CJMCU.h"
#include "../lib/Modbus/Modbus.hpp"
#include "Adafruit_CCS811.h"
#include "Adafruit_GFX.h"
#include "ESP32httpUpdate.h"

// Set serial for debug console (to Serial Monitor, default speed 115200)
#define SerialMon Serial
// Set serial for AT commands (to SIM800 module)
#define SerialAT Serial1

// Configure TinyGSM library
#define TINY_GSM_MODEM_SIM7070  // Modem is SIM800
#define TINY_GSM_RX_BUFFER 1024 // Set RX buffer to 1Kb
#include <TinyGsmClient.h>

// #define DUMP_AT_COMMANDS
#ifdef DUMP_AT_COMMANDS
#include <StreamDebugger.h>
StreamDebugger debugger(SerialAT, SerialMon);
TinyGsm modem(debugger);
#else
TinyGsm modem(SerialAT);
#endif
// clang-format off
// upload_speed 921600
// board esp32dev

#ifndef _IBOXLORA_H
#define _IBOXLORA_H

#include <stdint.h>

#define CFG_sx1276_radio 1 // HPD13A LoRa SoC



#endif
TinyGsmClientSecure client(modem);
#define PROTOCOL_4G
#include <../lib/PublishersClient.h>
#include <../lib/SlaveController.h>
#include <SPI.h>
#include <SD.h>
#include <Ticker.h>
#include "../lib/GPS.hpp"
#include "../lib/OTA/OTAUpdate.hpp"
#include <../lib/Sensor.h>
byte arrayData[52]; // array Data
// EL USO DE ARRAY DATA ES:
// 8 primeros BYTES PARA DATOS DE VALORES DE SENSORES
// 8 SIGUIENTES PARA TIPO EN ORDEN DE VALORES
// 8 SIGUIENTES PARA UNIDAD EN ORDEN DE VALORES


Sensor sensorsModbus[4];
byte slaves[128]; // array para guardar los sensores

SlaveController slaveController(21, 22);
unsigned long mill = 0;

#define TTGO_SOFTWARE_SERIAL 1 // If use ttgo
#define SENSOR_SUELO 1         // If we have sensor floor
#define SENSOR_NOISE 1         // If we have sensor floor

#ifdef SENSOR_SUELO
//#define sensorPowerController 1
//#define adapterModbusPowerController 1
//#define DEBUG 1
#if defined(TTGO_SOFTWARE_SERIAL)
#include <SoftwareSerial.h>
#ifdef TTGO_SOFTWARE_SERIAL
const int SSRxPin = 15; // 2 Recieve pin for software serial (Rx on RS485 adapter)
const int SSTxPin = 13; // 3 Send pin for software serial (Tx on RS485 adapter)
#endif
SoftwareSerial modbusSerial(SSRxPin, SSTxPin);
#else
HardwareSerial modbusSerial = Serial1;
#endif
#endif

void initModbus();
uint8_t* getModbusData();
uint32_t knownCRC32 = 0xD9971BA9;
// Construct the modbus instance
Modbus modbus;

// OTA
void updateFromFS();
void printPercent(uint32_t readLength, uint32_t contentLength);

void listDir(fs::FS &fs, const char *dirname, uint8_t levels);

const int portServer = 443;
const char resource[] = "/firmware.bin"; //here de bin file

uint32_t knownFileSize = 1024; // In case server does not send it
void performUpdate(Stream &updateSource, size_t updateSize);
void readFile(fs::FS &fs, const char *path);

long contentLength; // How many bytes of data the .bin is
bool isValidContentType = false;
int readLength = 0;
GPS gps;
void initModbus();
void timer();
void setup()
{
  Serial.begin(115200);
  // gps.init();

  publisher->initPublisher();

  slaveController.initMaster();
  // initCJM();
  OTAUpd.init();
  initModbus();

}
bool key = true;
void loop()
{
  // float *coords = gps.getCoords();
  // gps.testLoop();

  if (publisher->join())
  {
  
    if(protocol4G.sendLinkMessage("deviceSync")){
         if (timerTrue(mill, 31000)){ 
      // envia los datos del modbus (Sensores conectados al modbus)
      byte *arrayData = getModbusData();
      #ifdef PROTOCOL_4G
            protocol4G.sendData(arrayData, 4);
      #endif
      #ifdef PROTOCOL_LORA
        Lora.sendData(&sendjob, arrayData, DATA_PORT, sizeof(arrayData));
      #endif
      delay(100);

      *slaves = slaveController.getSlaves(); // obtiene el array de esclavos
      // recoge medidas de todos los esclavos disponibles
      for(int i = 0;i<128;i ++){
        if(slaves[i] != 0){
          Serial.print("Waking up sensors from slave: 0x");
          Serial.println(slaves[i], HEX);
          
          // despiera a todos los sensores de los esclavos y toman medidas
          slaveController.wakeUpSlaveAndTakeMeasures(slaves[i]);
        }
      }
      timer();

      for(int i = 0;i<128;i ++){
        if(slaves[i] != 0){
          Serial.print("Requesting sensors data from slave: 0x");
          Serial.println(slaves[i], HEX);
          uint8_t bytesToRequest = 24;
          byte *arrayData = slaveController.getMeasuresArrayFromSlave(slaves[i], bytesToRequest);
          printBytesArray(arrayData, bytesToRequest);

          #ifdef PROTOCOL_4G
            protocol4G.sendData(arrayData, 5);
          #endif
          #ifdef PROTOCOL_LORA
            Lora.sendData(&sendjob, arrayData, DATA_PORT, sizeof(arrayData));
          #endif
          delay(10);
          slaves[i] = 0;
        }
      }
      Serial.println("Requesting in 10 seconds");
      mill = millis();
    }
  }
}}

void timer(){
  Serial.println("Waiting 15 seconds");
  bool waiting = false;
  while (true)
  {
    #ifdef PROTOCOL_4G
      mqttClient.poll();
    #endif
      // puede recibir suscripciones mqtt mientras lee de los archivos
    if (timerTrue(millSensorsRequest, 15000))
    {
        if (waiting)
        {
            millSensorsRequest = millis();
            waiting = false;
            break;
        }
        if (!waiting)
            waiting = true;

        millSensorsRequest = millis();
    }
  }
}

void initModbus()
{

#ifdef SENSOR_SUELO
// Controller Modbus interface
#ifdef TTGO_SOFTWARE_SERIAL
  if (DEREPin >= 0)
  {
    pinMode(DEREPin, OUTPUT);
  }
#endif
  // Controller PowerPin Sensor
#ifdef sensorPowerController
  if (sensorPwrPin >= 0)
  {
    pinMode(sensorPwrPin, OUTPUT);
    digitalWrite(sensorPwrPin, HIGH);
  }
#endif
  // Controller power modbus interface
#ifdef adapterModbusPowerController
  if (adapterPwrPin >= 0)
  {
    pinMode(adapterPwrPin, OUTPUT);
    digitalWrite(adapterPwrPin, HIGH);
  }
#endif

  // Turn on modbus serial port
#if defined(TTGO_SOFTWARE_SERIAL)
  modbusSerial.begin(9600);
#else
  Serial1.begin(modbusBaudRate, SERIAL_8O1);
#endif
  modbus.begin(0x01, modbusSerial, DEREPin);
#endif

#ifdef SENSOR_NOISE
  modbus.changeAddrNoise();
#endif
}

/**
 * Devuelve un array con las mediciones de los sensores por modbus
 * @return devuelve el array 
 */ 
byte *getModbusData()
{
  byte *arrayData = new byte[52];
  byte temp = modbus.getTemperature();
  Serial.print("Temperatura: ");
  Serial.println((uint8_t)temp);
  arrayData[0] = temp;
  arrayData[0+8] = 0x50; // identificador TEMP
  arrayData[0+16] = 0x10; // identificador Cº

  byte epsi = modbus.getEpsilon();
  Serial.print("Epsilon: ");
  Serial.println((uint8_t)epsi);
  arrayData[1] = epsi;
  arrayData[1+8] = 0x52; // identificador EPSI
  arrayData[1+16] = 0x11; // identificador EPSI

  byte soil = modbus.getSoilMoisture();
  Serial.print("Soil: ");
  Serial.println((uint8_t)soil);
  arrayData[2] = soil;
  arrayData[2+8] = 0x53; // identificador SOIL
  arrayData[2+16] = 0x08; // identificador EPSI

  byte noise = modbus.getNoise();
  Serial.print("Noise: ");
  Serial.println((uint8_t)noise);
  arrayData[3] = noise;
  arrayData[3+8] = 0x51; // identificador NOISE
  arrayData[3+16] = 0x12; // identificador DB

  return arrayData;
            
}

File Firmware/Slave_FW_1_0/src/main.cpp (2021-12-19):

// -*- mode: c++ -*-
// --------------------------------------------------------------
// Autor: Yeray Candel Sampedro
// Date: 16 - 10 - 2021
//
// Description: El archivo main se encarga de gestionar mediante
// el arduino nano todos los sensores actualmente conectados
// a este mediante UART.
// --------------------------------------------------------------

#include <Arduino.h>
#include <Wire.h>
#include <SoftwareSerial.h>
unsigned long mill = 0;

bool timerTrue(unsigned long lastmillis_, int interval)
{
  if (millis() > (lastmillis_ + interval))
    return true;

  return false;
}

#include <../lib/SensorUART.h>

// function that executes whenever data is received from master
// this function is registered as an event, see setup()

const byte I2C_SLAVE_ADDR = 0x20;

// comandos
const byte REQUEST_COMMAND = 0x30;

uint8_t arrayLength = 8;
byte *arrayData1 = new byte[arrayLength];
byte *arrayData2 = new byte[arrayLength];
byte *arrayData3 = new byte[arrayLength];
void wakeUpSensors();
void sleepSensors();
void requestDataSensors();
void resetArrayData();
bool wakedUP = false;
void requestSensorsInformation();

// para TVOC necesito 9 bits 2 BYTEs
// para H2 necesito 10 bits 2 Bytes
// para CO necesito 10 bits 2 bytes
// para H2S necesito 7 bits 1 bytes
// para CL2 necesito 6 buts 1 byte
// para O3 necesito 7 bits 1 byte
// para NO2 necesito 10 bits 2 bytes
// para SO2 necesito 10 bits 2 bytes
// para CH4S necesito 7 bits 1 byte
// para NH3 necesito 10 bits 2 bytes
// para Temp necesito 5 bits 1 byte
// para Hum necesito 7 bits 1 byte
// total 103 bits = 13 bytes // 18 sin juntar todos los bits

SensorUART sensor1(11, 10);
SensorUART sensor2(9, 8);
SensorUART sensor3(5, 4);
SensorUART sensor4(7, 6);
SensorUART sensor5(3, 2);

SoftwareSerial serialtest(11, 10);
SoftwareSerial serialtest2(9, 8);
SoftwareSerial serialtest3(5, 4);
SoftwareSerial serialtest4(7, 6);
SoftwareSerial serialtest5(3, 2);

byte data = 0;

void resetSensors()
{

  sensor1.reset();
  sensor2.reset();
  sensor3.reset();
  sensor4.reset();
  sensor5.reset();

  data = 0;
}

// Request event para enviar los datos
// esta funcion es llamada por el maestro
void requestEvent()
{
  Wire.flush();
  resetSensors();
  wakedUP = false;

  Serial.println("Requested data from Master...");

  // envia el primer array con la medida de los sensores
  Wire.write(arrayData1, arrayLength);
  Wire.flush();
  delay(10);

  // envia el segundo array con el tipo de sensor
  Wire.write(arrayData2, arrayLength);
  Wire.flush();
  delay(10);

  // envia el tercer array con el tipo de medida del sensor
  Wire.write(arrayData3, arrayLength);
  delay(10);
  Wire.flush();
  Serial.println("Data sended");
  Serial.println();
}

void resetArrayData()
{
  sensor1.resetArrays();
  sensor2.resetArrays();
  sensor3.resetArrays();
  sensor4.resetArrays();
  sensor5.resetArrays();
}

// Funcion para recibir comandos desde el master
void receiveEvent(int bytes)
{
  resetArrayData();
  Wire.flush();
  data = 0;
  uint8_t index = 0;
  Serial.println("Received instruction from Master");
  // lee el comando
  while (Wire.available())
  {
    byte *pointer = (byte *)&data;
    *(pointer + index) = (byte)Wire.read();
    index++;
  }
}

// inicializa los sensores
void initSensors()
{
  serialtest.begin(9600);
  serialtest2.begin(9600);
  serialtest3.begin(9600);
  serialtest4.begin(9600);
  serialtest5.begin(9600);

  sensor1.initSensor(9600);
  sensor2.initSensor(9600);
  sensor3.initSensor(9600);
  sensor4.initSensor(9600);
  sensor5.initSensor(9600);
  Serial.println("Initialized Sensors");
}

void setup()
{
  Serial.begin(9600);
  Serial.println("Initialized Slave");
  initSensors();
  wakeUpSensors();

  Wire.begin(I2C_SLAVE_ADDR);
  Wire.onRequest(requestEvent);
  Wire.onReceive(receiveEvent);
  Serial.println("Initialized I2C Communication");
}

void loop()
{

  if (data != 0)
  {
    Serial.print("Command received: 0x");
    Serial.println(data, HEX);

    if (data == REQUEST_COMMAND)
    {
      wakeUpSensors();

      if (wakedUP)
      {
        delay(5200);
        requestSensorsInformation();
        delay(1000);
        requestDataSensors();
      }

      // rellenando el array
      arrayData1[0] = sensor1.getGasConcentration();
      arrayData1[1] = sensor2.getGasConcentration();
      arrayData1[2] = sensor3.getGasConcentration();
      arrayData1[3] = sensor4.getGasConcentration();
      arrayData1[4] = sensor5.getGasConcentration();
      arrayData1[5] = 1;
      arrayData1[6] = 1;
      arrayData1[7] = 1;
      delay(10);
      arrayData2[0] = sensor1.getType();
      arrayData2[1] = sensor2.getType();
      arrayData2[2] = sensor3.getType();
      arrayData2[3] = sensor4.getType();
      arrayData2[4] = sensor5.getType();
      arrayData2[5] = 2;
      arrayData2[6] = 2;
      arrayData2[7] = 2;
      delay(10);

      arrayData3[0] = sensor1.getUnit();
      arrayData3[1] = sensor2.getUnit();
      arrayData3[2] = sensor3.getUnit();
      arrayData3[3] = sensor4.getUnit();
      arrayData3[4] = sensor5.getUnit();
      arrayData3[5] = 3;
      arrayData3[6] = 3;
      arrayData3[7] = 3;
      delay(10);

      for (int i = 0; i < arrayLength; i++)
      {
        if (i < 5)
          Serial.print("Sensor " + String(i + 1) + ": ");
        Serial.print(arrayData1[i]);
        Serial.print(".");
        Serial.print(arrayData2[i]);
        Serial.print(".");
        Serial.print(arrayData3[i]);
        Serial.println();
      }
      // ejecutar el comando
    }
  }
}

// Pide la informacion del tipo de sensor, unidades en las que mide, etc.  a todos los sensores
void requestSensorsInformation()
{

  sensor1.getInformation();
  sensor2.getInformation();
  sensor3.getInformation();
  sensor4.getInformation();
  sensor5.getInformation();
  data = 0;
  resetSensors();
}

// pide las medidas a todos los sensores
void requestDataSensors()
{
  sensor1.getMeasure();
  sensor2.getMeasure();
  sensor3.getMeasure();
  sensor4.getMeasure();
  sensor5.getMeasure();
  data = 0;
  resetSensors();
  // sleepSensors();
}
// despierta a todos los sensores
void wakeUpSensors()
{

  sensor1.wakeUp();
  sensor2.wakeUp();
  sensor3.wakeUp();
  sensor4.wakeUp();
  sensor5.wakeUp();
  resetSensors();
  wakedUP = true;
}

// funcion que duerme a todos los sensores
void sleepSensors()
{
  sensor1.sleep();
  sensor2.sleep();
  sensor3.sleep();
  sensor4.sleep();
  sensor5.sleep();
  resetSensors();
  wakedUP = false;
}

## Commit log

2021-11-03 Init Publisher y Joined creados en 4G. Arreglados bugs clase Publisher
    [Protocol4G.h, main.cpp]
2021-11-03 Añadido protocolo MQTT de envio de datos y Recepcion de datos.
2021-11-04 Hardware update
    [PlacaSlave3AGesinen.kicad_pcb, PlacaSlave3AGesinen.sch]
2021-11-09 Cambiada la placa del esclavo
2021-11-09 Optimizacion de la clase Publicadores + Main + creado PublicadoresClient y Utils.h
2021-11-16 Optimized Slave Controller
    Working commit I2C
2021-11-22 Primer test software serial
    Funcionando con 2 arduinos.
2021-11-23 SensorUART class implementada
2021-11-23 getType y getMeasure Implementados
    Añadidos testUart, y se han testeado 5 UARTS
2021-11-24 Solved Error Writing Data to I2C with UART (Simulated)
    [main.cpp]
2021-11-24 Update finished Hardware
    [Master3A-2021-11-22-13-45-35.sch, Master3A.kicad_pcb, Master3A.sch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]
2021-11-26 Squashed commit of the following:
    commit dc66c705c26bb8546bf42e4e2412be2f97287fa4
    Author: Yeray Candel <ycansam@epsg.upv.es>
    Date: Fri Nov 26 01:18:12 2021 +0100
    ModBuss Implementado
    commit e472c0fb496fb5f31392eb650849038dd407901c
    Author: Daniel Burruchaga <dbs99@hotmail.com>
    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
    [Master3A-2021-11-22-13-45-35.sch, Master3A.kicad_pcb, Master3A.sch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]
2021-12-01 v1.0.1
    Todos los cambios comprobados y funcionando con la sim 7000G
2021-12-14 Sensores leidos con la libreria
2021-12-15 Los sensores ya se leen correctamente con peticiones del master
    [main.cpp]
2021-12-15 Sensores Duermiendo Despertando Leyendo y Despertando
2021-12-16 Los Sensores se duermen, se despiertan, leen y se duermen con el master
2021-12-16 comit 4 de la mañana casi 5
2021-12-16 Update OTA to MASTER working (Culpa de yeray que no funcione)
2021-12-16 add working Sensor Modbus, floorSensor, noiseSensor
    Esta funcionando Lora, OTA Update , Modbus, Recoger Datos slave, enviarlos por 4g
    [main.cpp]
2021-12-17 Maestro lee el tipo de sensor y las unidades
2021-12-17 Los sensores se actualizan al intercambiarse en cualquier momento
2021-12-17 El maestro lee hasta un maximo de 127 esclavos
    Envia las mediciones de cada 1 de los esclavos por mqtt en 4G
2021-12-19 SYNCRONIZED WORKING
    Ahora se vincula con la plataforma
2021-12-19 Arreglado OTA UPDATE y Refactorizado maestro
    [main.cpp]
2021-12-19 Fix Slave Measures Analyzer
    [main.cpp]
2022-01-13 doc tecnica
    [BATERIA PANASONIC.xlsx, InstalacionAras.xlsx]
